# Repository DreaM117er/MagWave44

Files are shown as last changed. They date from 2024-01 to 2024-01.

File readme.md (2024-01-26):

# MagWave44

- 中文說明（Chinese Readme）。
- [英文說明（English Readme）](readme_en.md)。

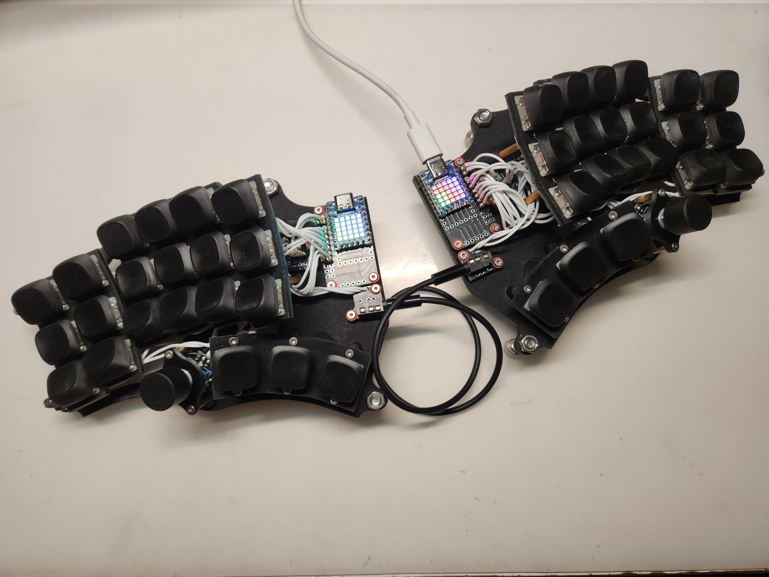
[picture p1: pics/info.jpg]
info


## 簡介

Dactyl Manuform系列的鍵盤有很多種不同的樣式、也有各式各樣的作者製作成屬於自己的曲面分離式鍵盤，但大部分的Manuform系列根據的都是原始的模型再製而成，而這些成品也不一定適合自己的雙手。而在手指長度上，無名指是屬於比較特殊的一根手指，長度介於中指跟食指之間、又或者跟食指一樣長、而又或者比食指要短都有可能，這就導致大部分的鍵盤設計在無名指上不是那麼的友好。

而我本人的手屬於無名指長介於中指及食指之間，因此根據我的雙手及原始的Dactyl Manuform設計了第一把曲面分離式鍵盤，並且使用矮軸降低鍵盤的厚度，而這把鍵盤卻有著十分難操作移動手指的致命缺失。

於是我根據這個失敗的模型重新再設計了一個模型，以iPhone用戶的外殼配件Magsafe及波浪（Wave）狀的外殼底板，再根據44鍵的按鍵總數，將這把鍵盤取名為MagWave44。

- 第一把鍵盤模型。
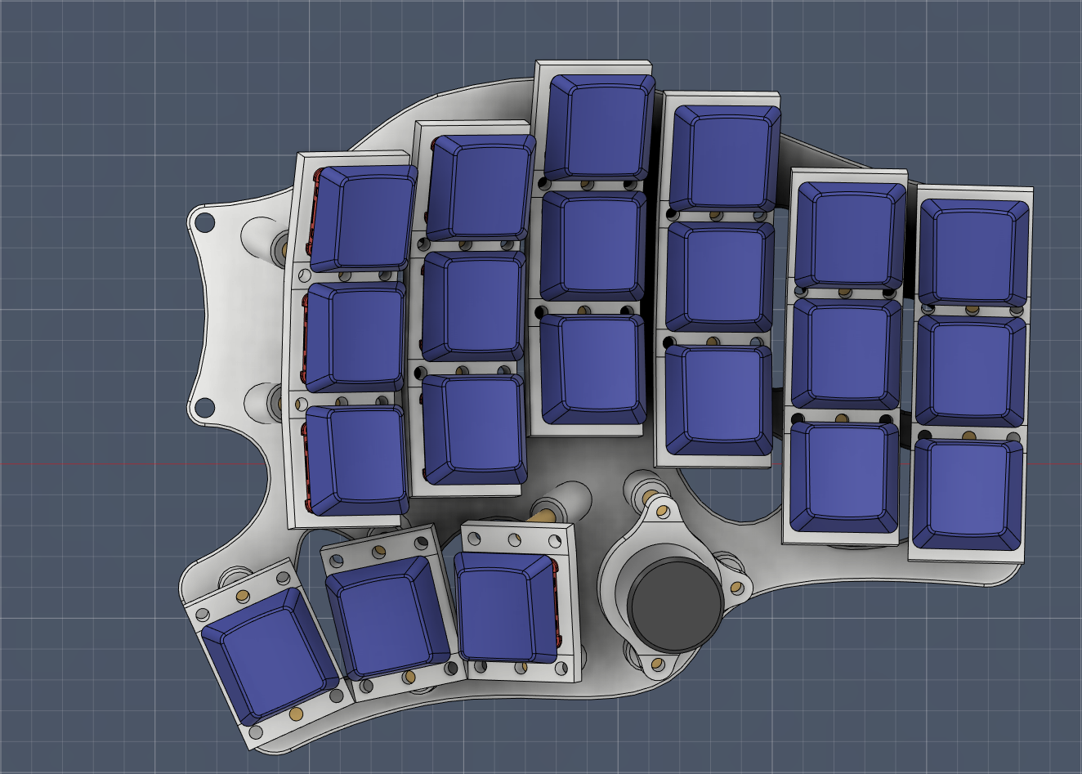
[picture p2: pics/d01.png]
des01


- 我的左手手指長度。
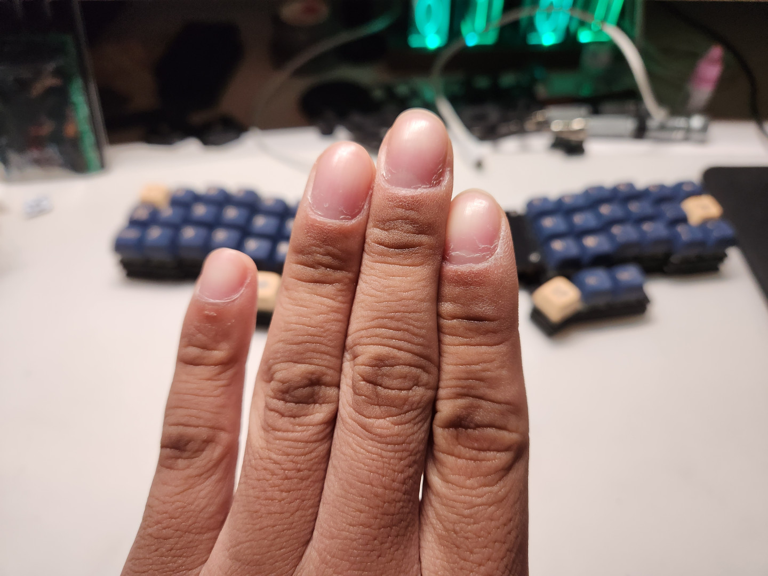
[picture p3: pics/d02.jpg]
des02


## 材料清單

### 3D列印部件

|名稱|數量|備註|照片|
|---|---|---|---|
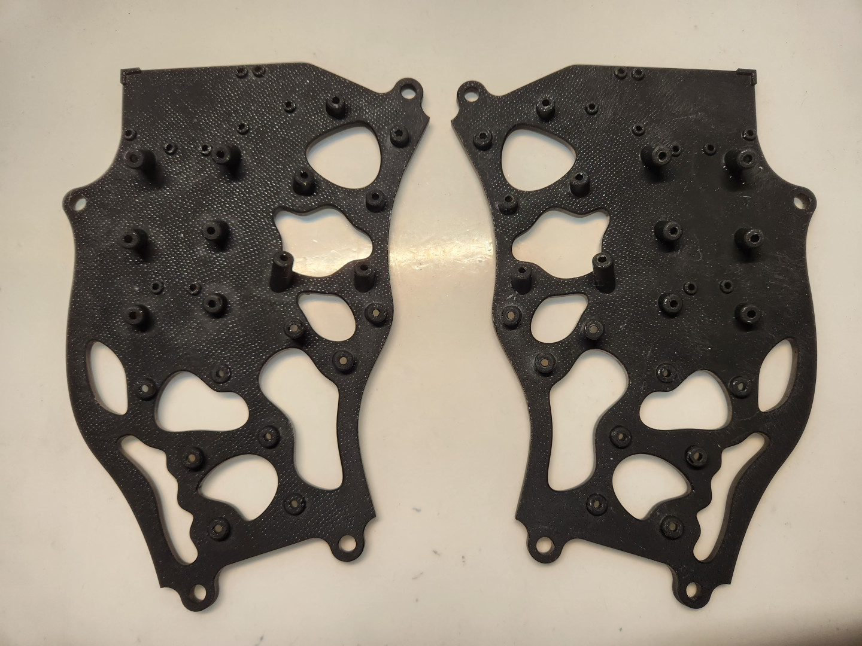
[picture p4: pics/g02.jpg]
|底板|1組|左右手||
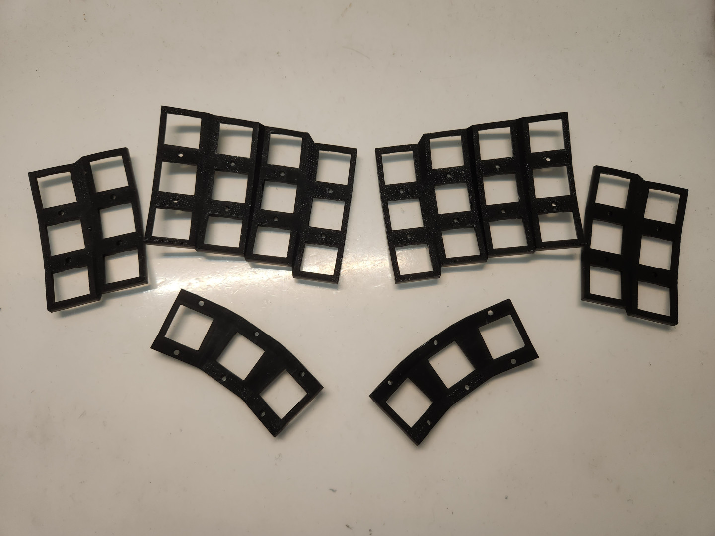
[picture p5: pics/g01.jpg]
|定位板|1組|左右手||
|旋鈕定位板|1-2片|-||
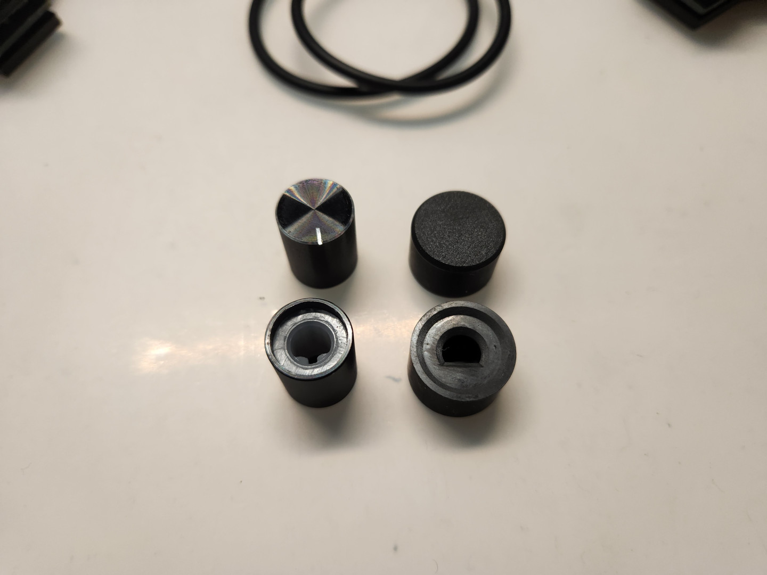
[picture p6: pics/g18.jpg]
|`D型`旋鈕帽|1-2個|-||

### 電路板

|名稱|數量|備註|正面|背面|
|---|---|---|---|---|
|單格電路板|42片|`矮軸`用|||
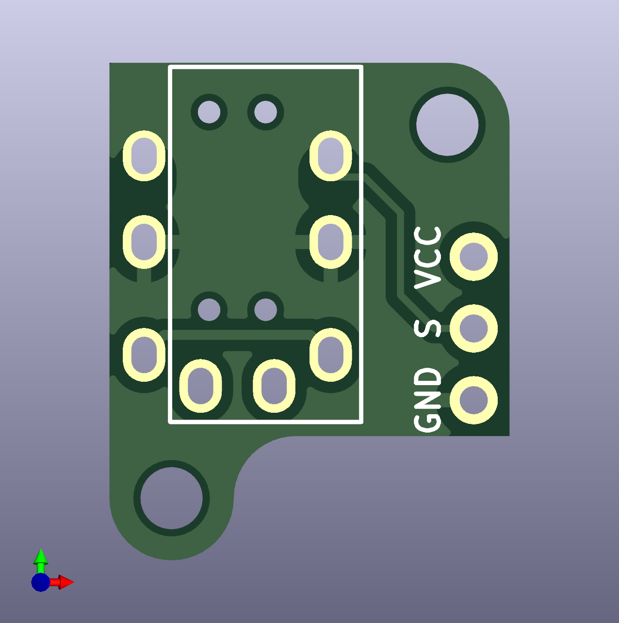
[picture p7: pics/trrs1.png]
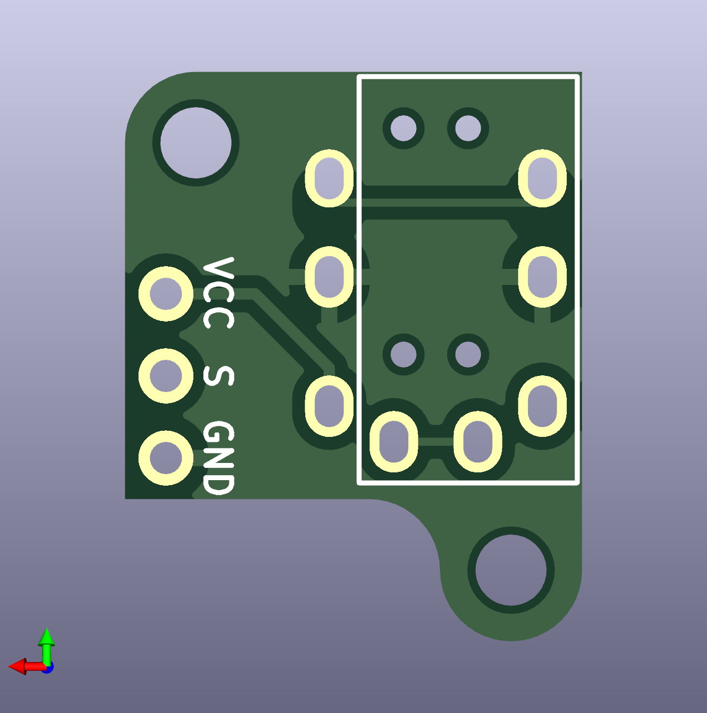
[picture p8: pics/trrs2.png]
|TRRS專用電路板|2片|-|||
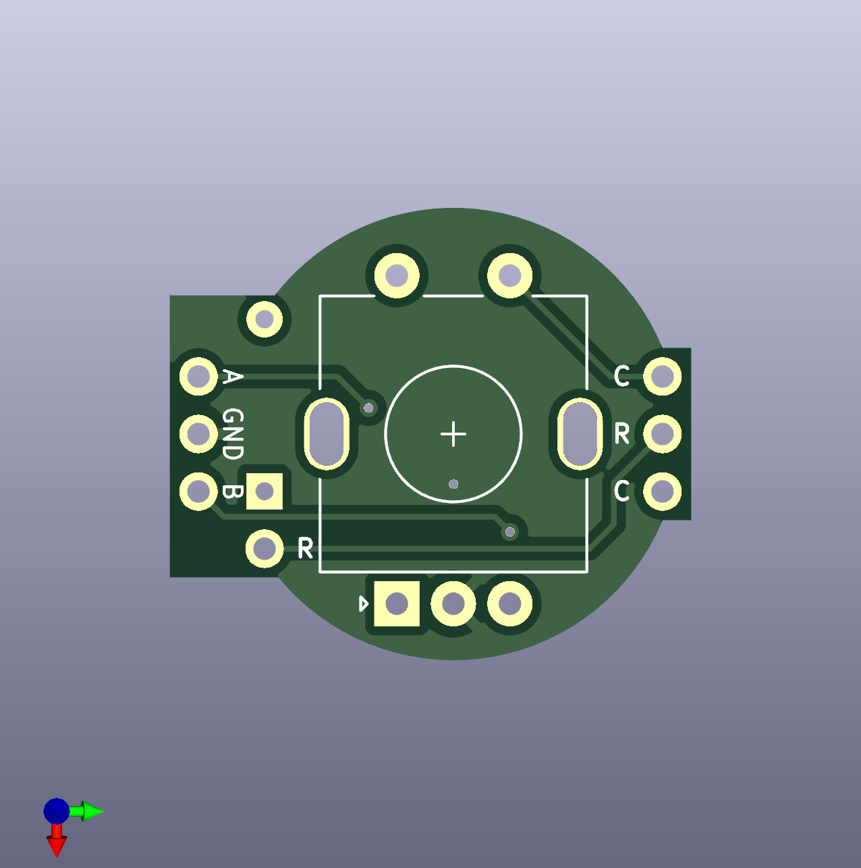
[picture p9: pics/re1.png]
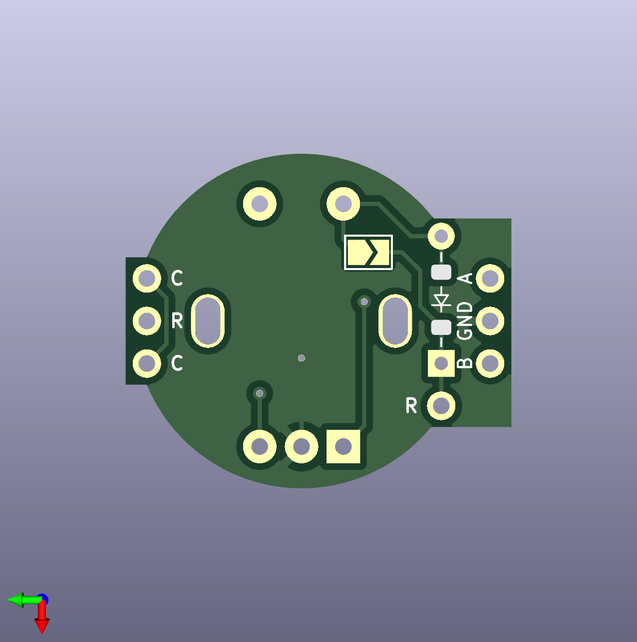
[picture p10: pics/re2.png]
|EC-11的專用電路板|1-2片|-|||
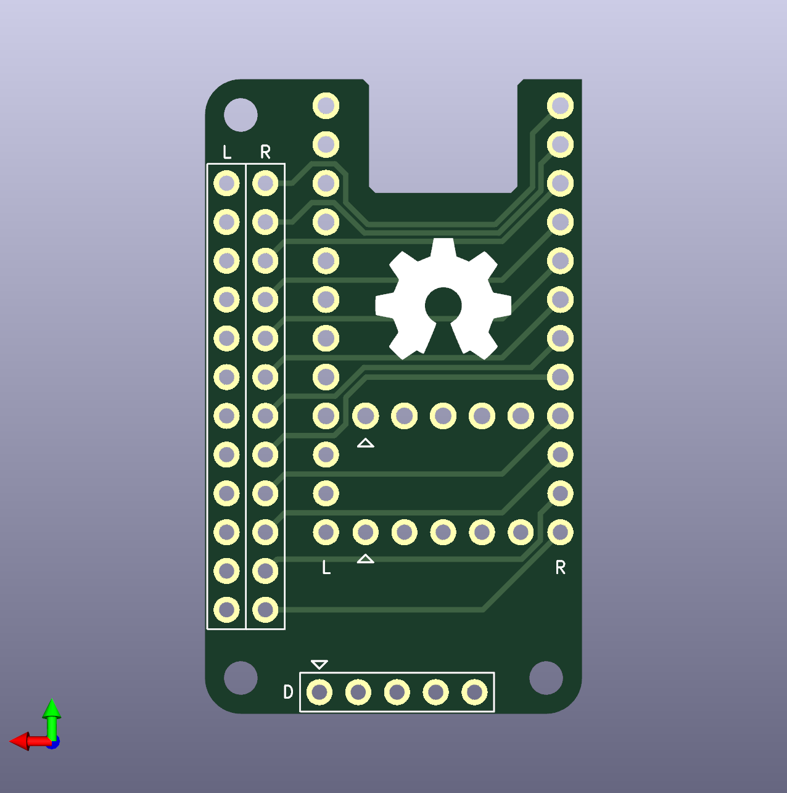
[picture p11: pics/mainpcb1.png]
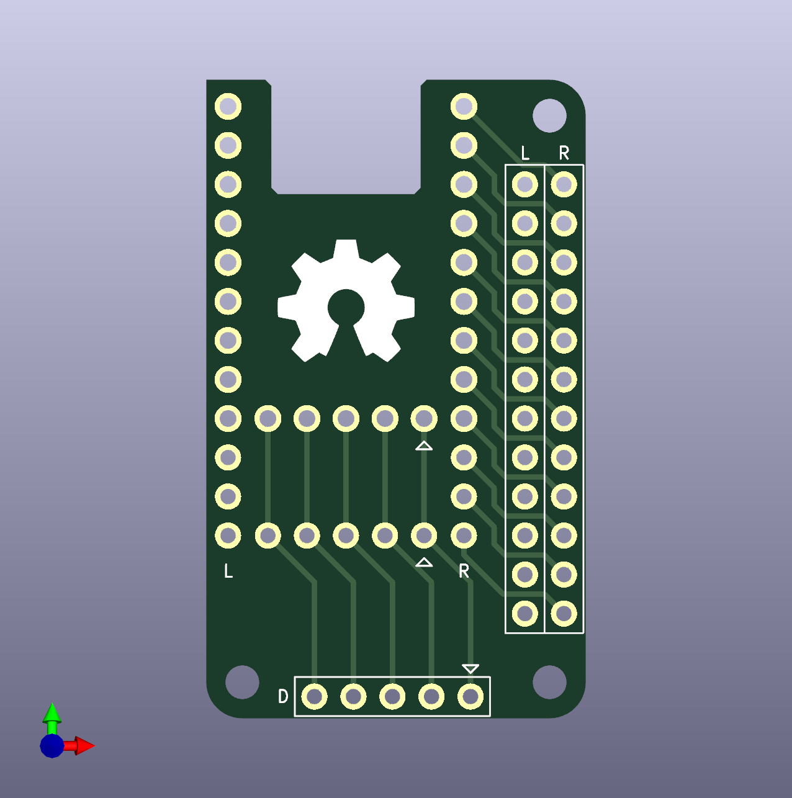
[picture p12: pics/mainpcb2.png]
|MCU電路板|2片|-|||
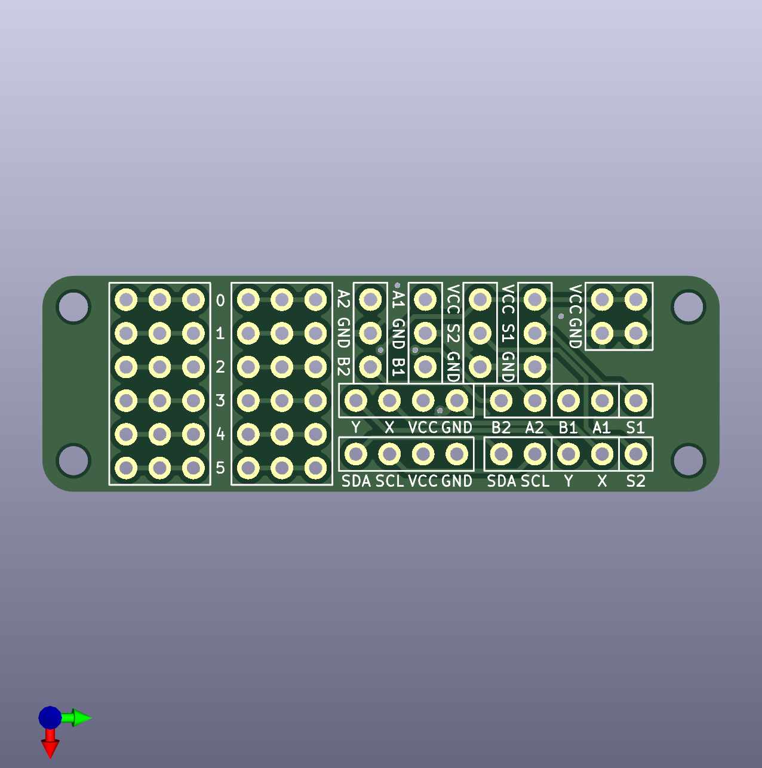
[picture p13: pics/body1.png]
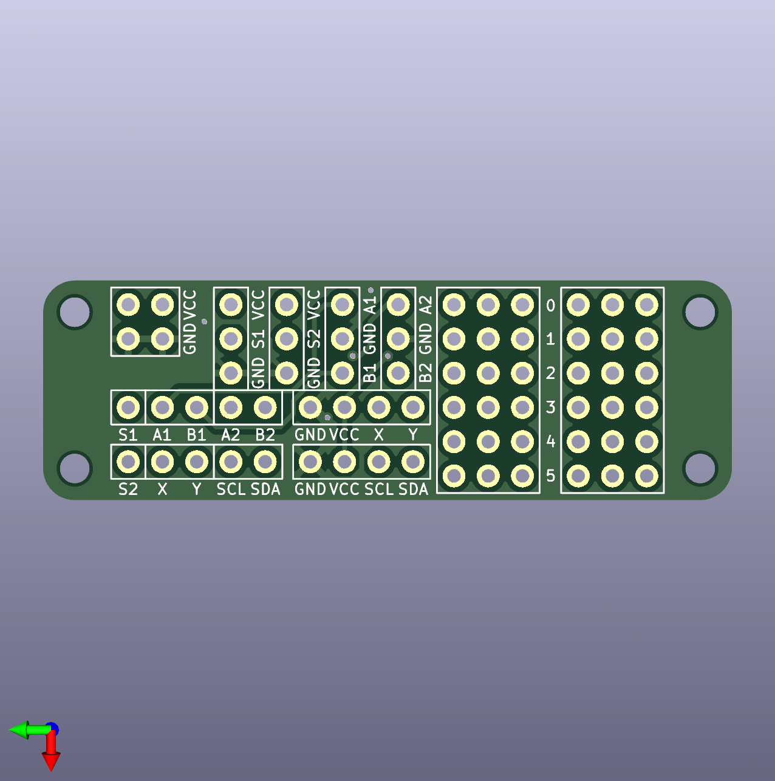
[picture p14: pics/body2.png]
|本體電路板|2片|-|||

### 螺絲零件

|名稱|數量|備註|
|---|---|---|
|微型控制器|2片|規格請查詢下方`Note`|
|`1N4148` 二極體|42-44個|`DO-35`或`SOD-123`都可|
|`TRRS`座|2個|-|
|公母圓`排針`|-|-|
|`M2x5mm` 扁頭螺絲|78-84根|-|
|`M2x8mm` 扁頭螺絲|18根|可選配，有電路板才需要|
|`M2` 六角螺母|18個|可選配，有電路板才需要|
|`M2x5mm` 雙通銅柱|16根|-|
|`M2x7mm` 雙通銅柱|8根|-|
|`M2x10mm` 雙通銅柱|6根|旋鈕零件，可選配|
|`M2x12mm` 雙通銅柱|8根|-|
|`M2x18mm` 雙通銅柱|4根|-|
|`D型` `EC-11` 旋鈕編碼器|1-2個|`高15mm`，可選配|
|`M5x8mm` 以上厚頭螺絲|8根|Tending用，可選配|
|`M5` 六角螺母|8-14個|Tending用，可選配|
|`Magsafe`引磁圈或吸磁環|2個|Tending用，可選配|
|電線或漆包線|-|-|
|矮軸|42個|-|
|1u鍵帽|42個|-|

> **Note**
>
> 可使用的微型控制器請依據自身需求做選擇，因為是完全開源的關係，你可以任意變更目前使用的GPIO腳位，如果想要按照現有韌體組裝安裝鍵盤的話，以下微型控制器是我納入清單內的，供大家參考：
> 
> ATMega32U4系列：`ProMicro 5V16M`、`Eltie-C v4`。
> 
> RP2040系列：`RP2040-ProMicro`、`RP2040-Zero`、`RP2040-Matrix`、`RP2040-SuperMini`。

## 製作前準備

> **Note**
>
> MagWave44為3D列印的曲面鍵盤，由於定位板在設計上專屬於矮軸，螺絲配件屬於比較小的M2規格，推薦使用LCD或SLA的列印機製作。

> **Note**
>
> 推薦使用工程用樹脂進行列印，確保鍵盤部件不會輕易斷裂及融化。

> **Note**
>
> 鍵盤韌體有4種可供選用，製作方式會以降低手拉線的難易度去介紹。

> **Warning**
>
> 個人操作3D列印機、使用電烙鐵工具等務必注意環境通風，避免中毒、火源、燒燙傷等危險。

- [點我進入組裝說明](guide.md)。

## 鍵盤配列

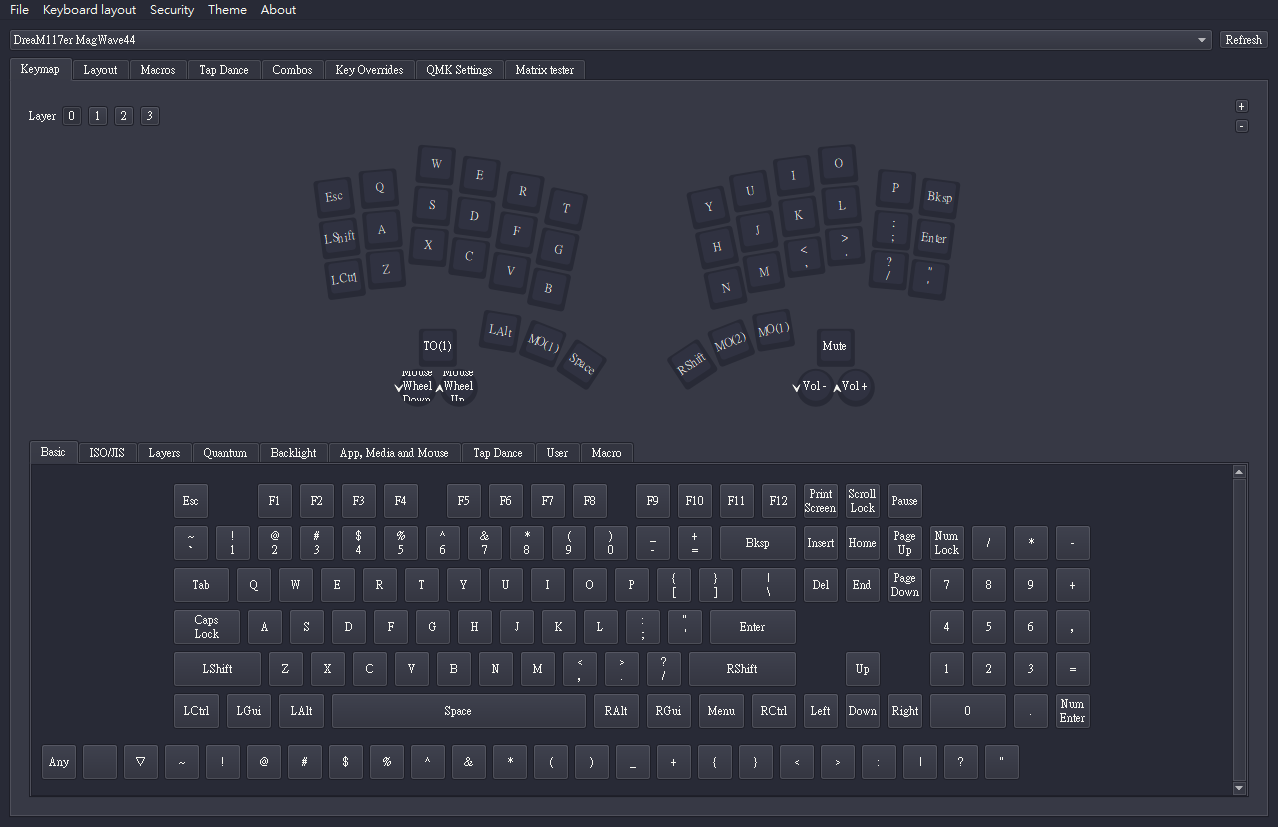
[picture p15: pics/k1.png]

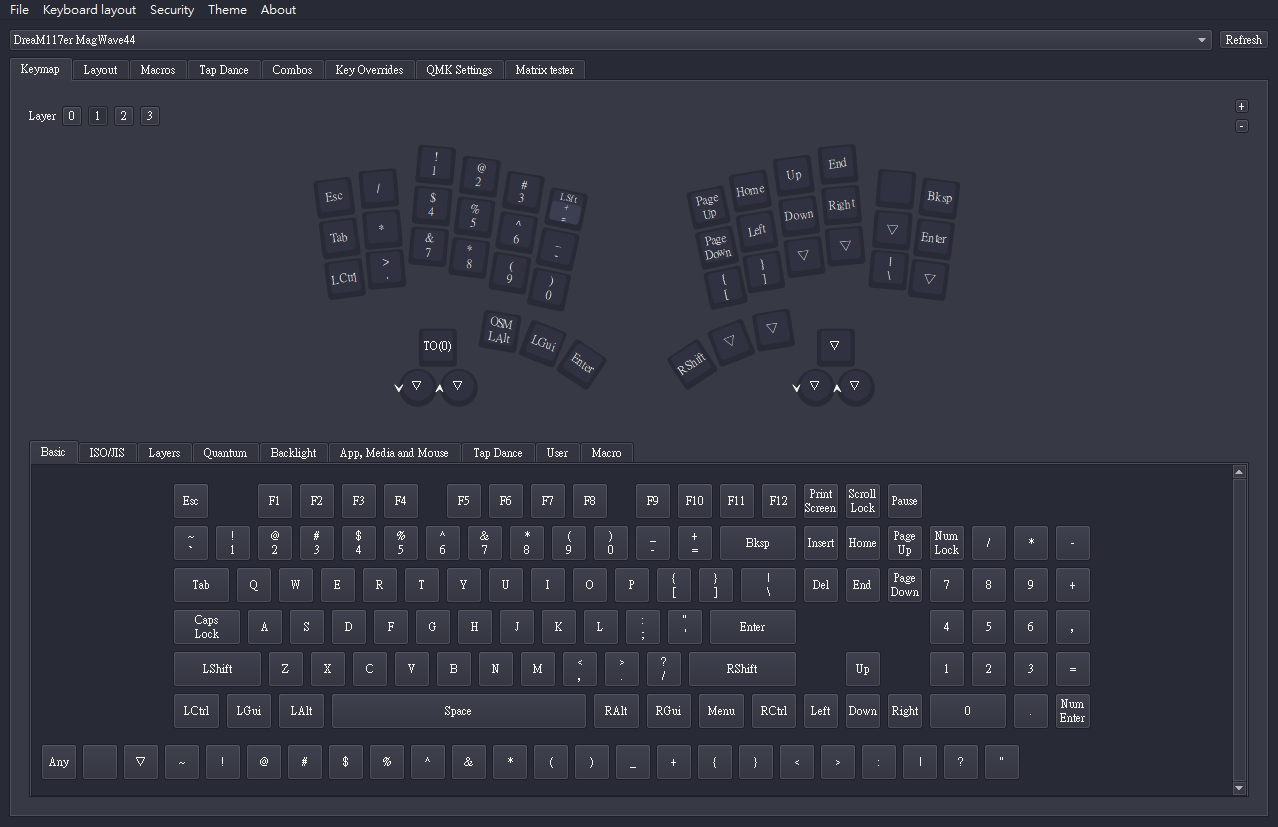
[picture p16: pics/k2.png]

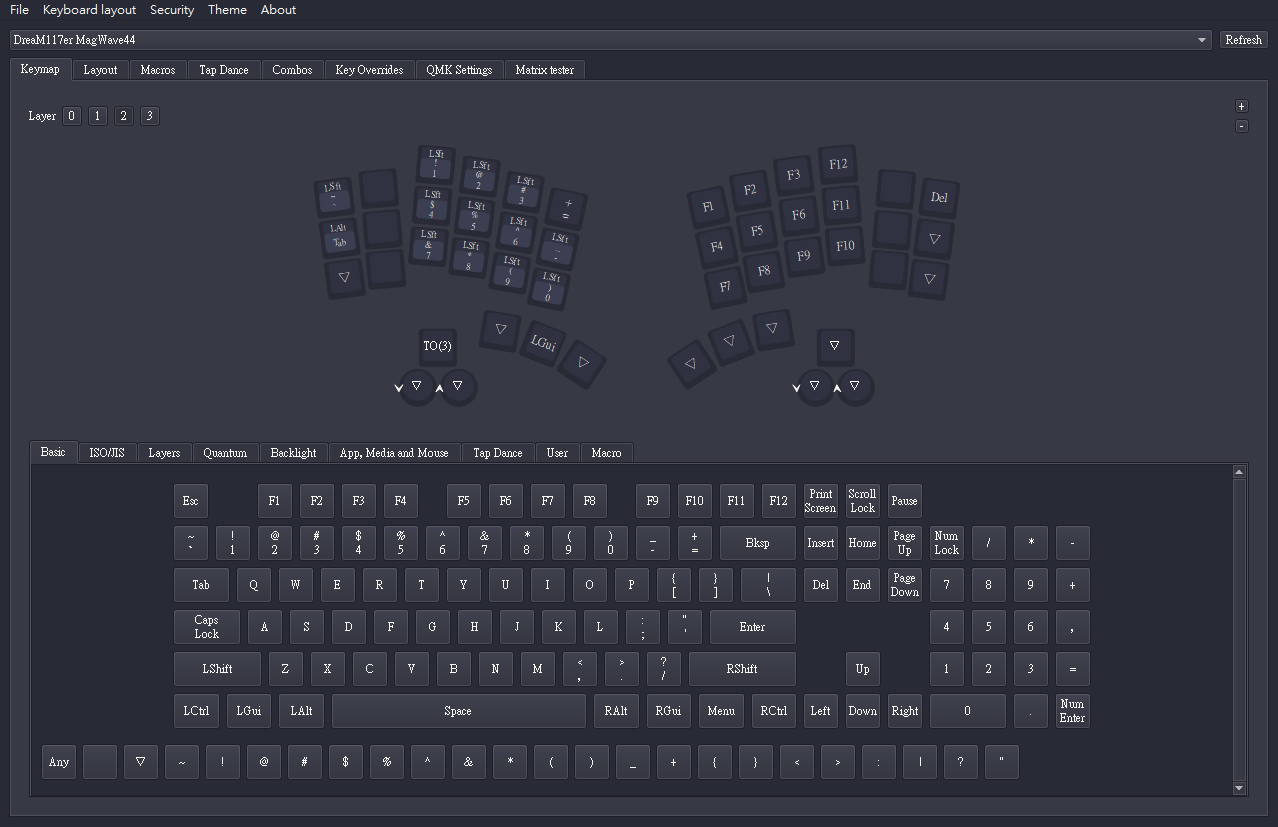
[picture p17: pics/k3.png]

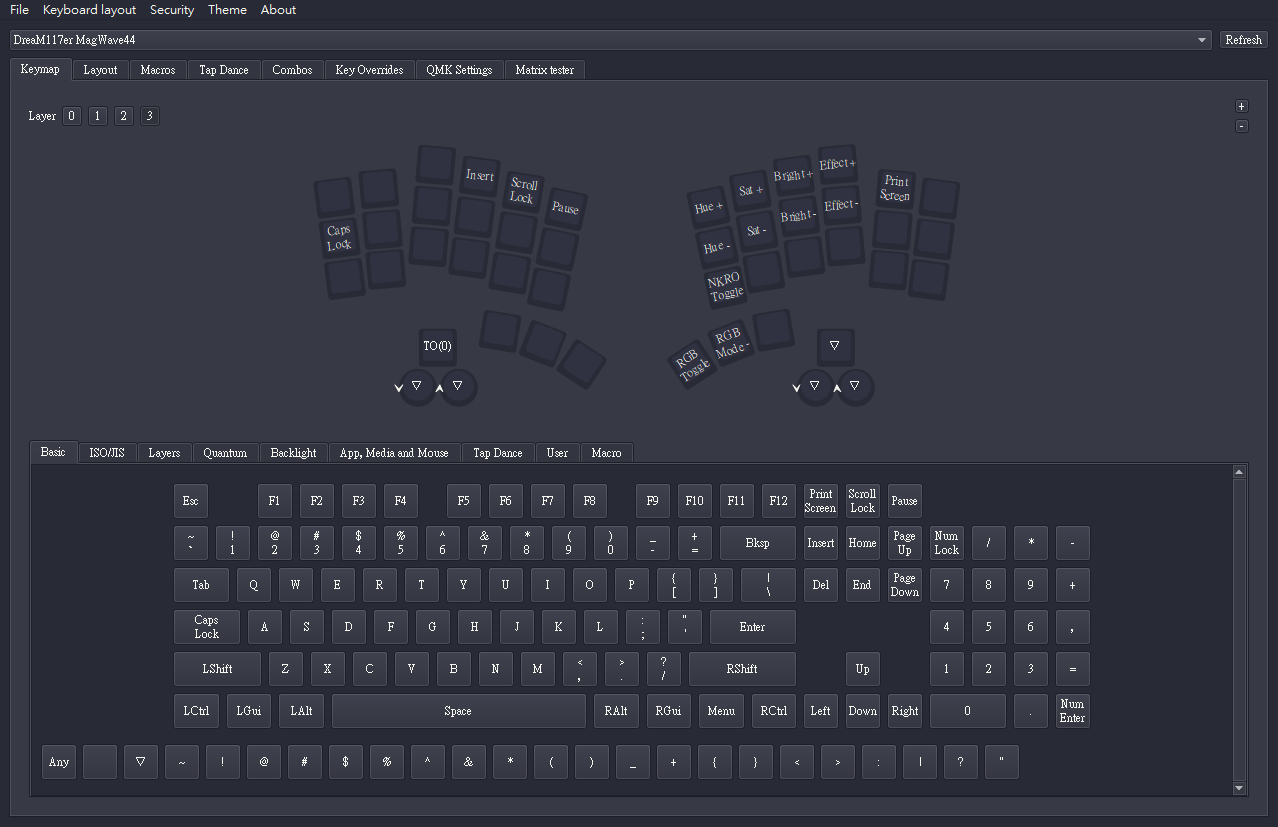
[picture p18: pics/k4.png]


## 參考及使用資料
- [QMK Firmware](https://qmk.fm/).
- [VIAL](https://get.vial.today/).
- [KiCAD](https://www.kicad.org/) version `7.0.5.`
- [JLCPCB](https://jlcpcb.com/).
- [DeepL](https://www.deepl.com/translator).
- [AutoDesk Fusion360](https://www.autodesk.com/products/fusion-360/free-trial).

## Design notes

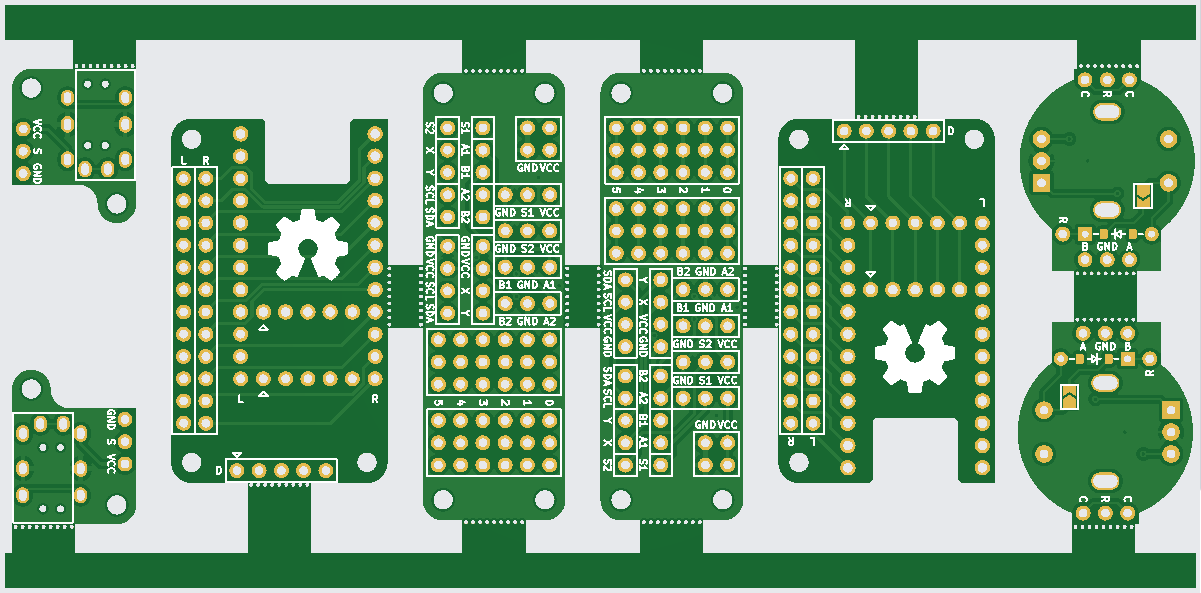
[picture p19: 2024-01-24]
pics/all1.png

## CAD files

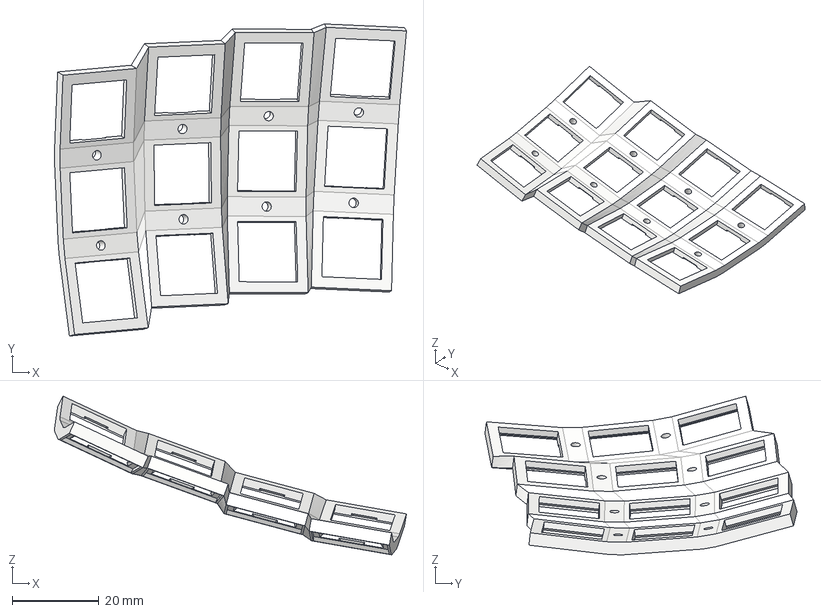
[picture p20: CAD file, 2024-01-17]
files/step/3x4 main plate.step
81.4 x 72.2 x 36.7 mm

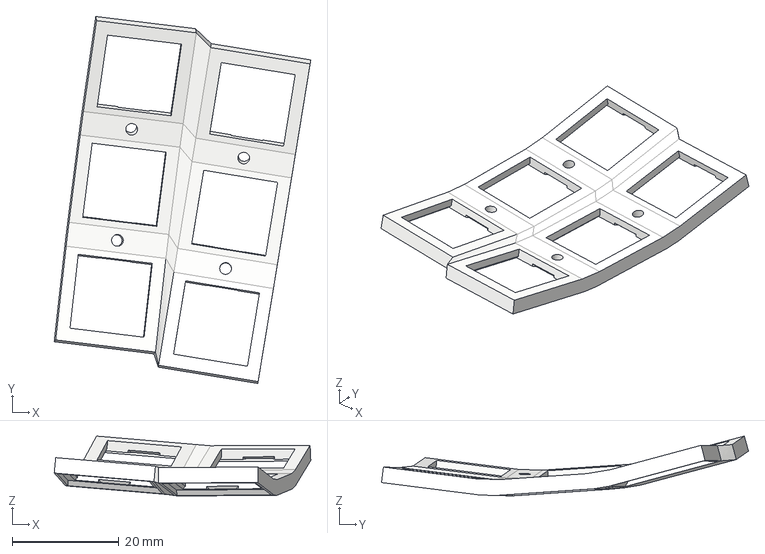
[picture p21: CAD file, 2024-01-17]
files/step/3x2 main plate.step
48.0 x 68.6 x 11.2 mm

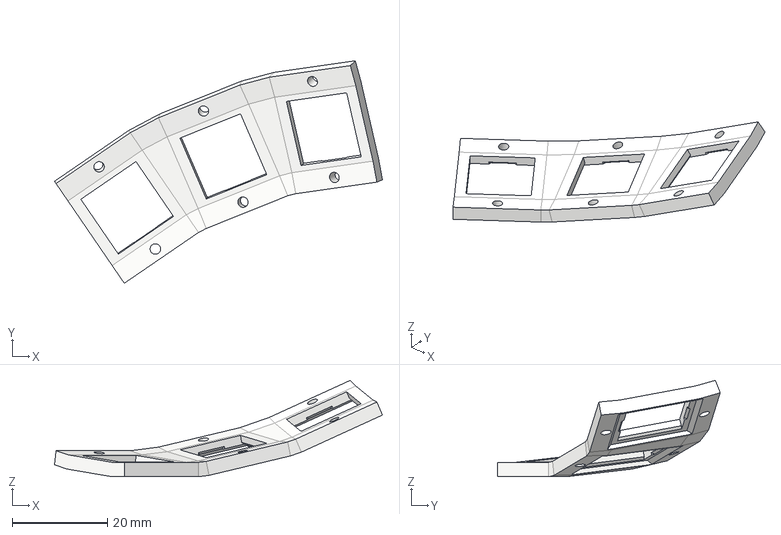
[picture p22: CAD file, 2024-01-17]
files/step/1x3 thumb plate.step
68.7 x 46.6 x 20.2 mm

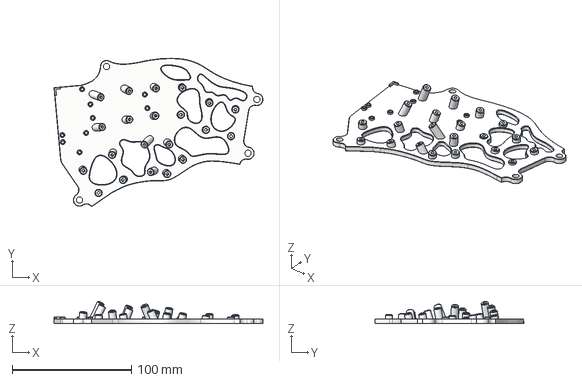
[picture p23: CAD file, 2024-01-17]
files/step/bottom.step
175.2 x 124.5 x 18.7 mm

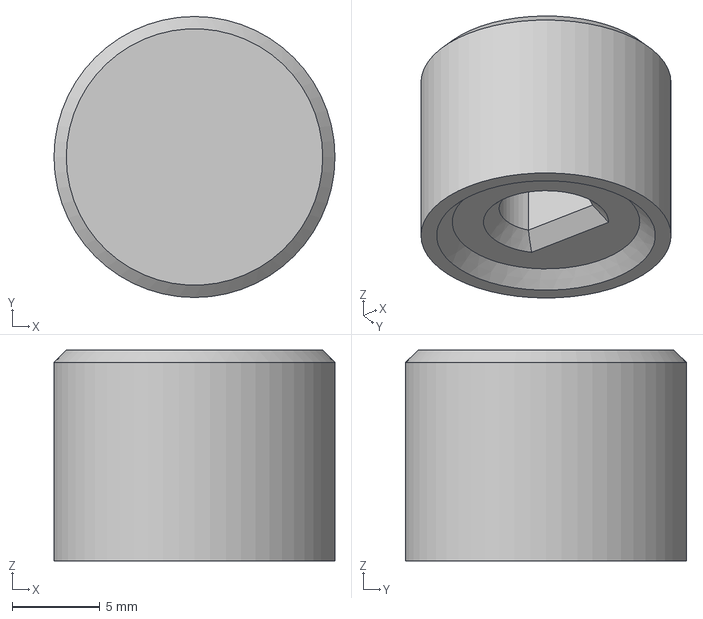
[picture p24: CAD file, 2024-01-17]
files/step/type-d h7.0mm.step
16.0 x 16.0 x 12.0 mm

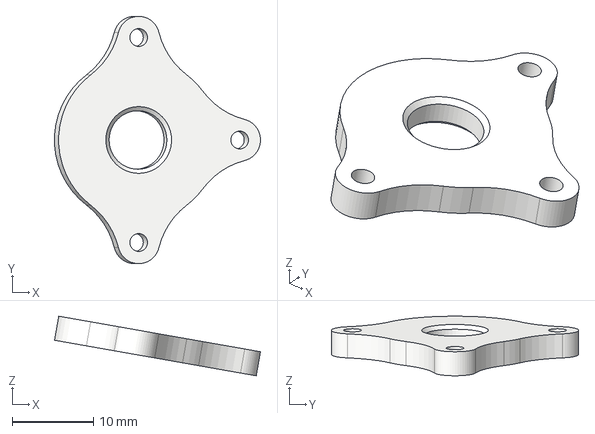
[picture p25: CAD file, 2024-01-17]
files/step/ec-11 plate.step
25.3 x 30.4 x 7.33 mm

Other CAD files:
files/stl/1x3 thumb plate.stl
files/stl/3x2 main plate.stl
files/stl/3x4 main plate.stl
files/stl/bottom.stl
files/stl/ec-11 plate.stl
files/stl/type-d h7.0mm.stl

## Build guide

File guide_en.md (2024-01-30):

# Building Guide

- [中文說明（Chinese Guide）](guide.md)。
- 英文說明（English Guide）。

## Pre-operation

- After printing out all the parts needed for the keyboard, first take out the bottom parts and spacers ,follow the photo instructions for installing the posts in their proper locations.

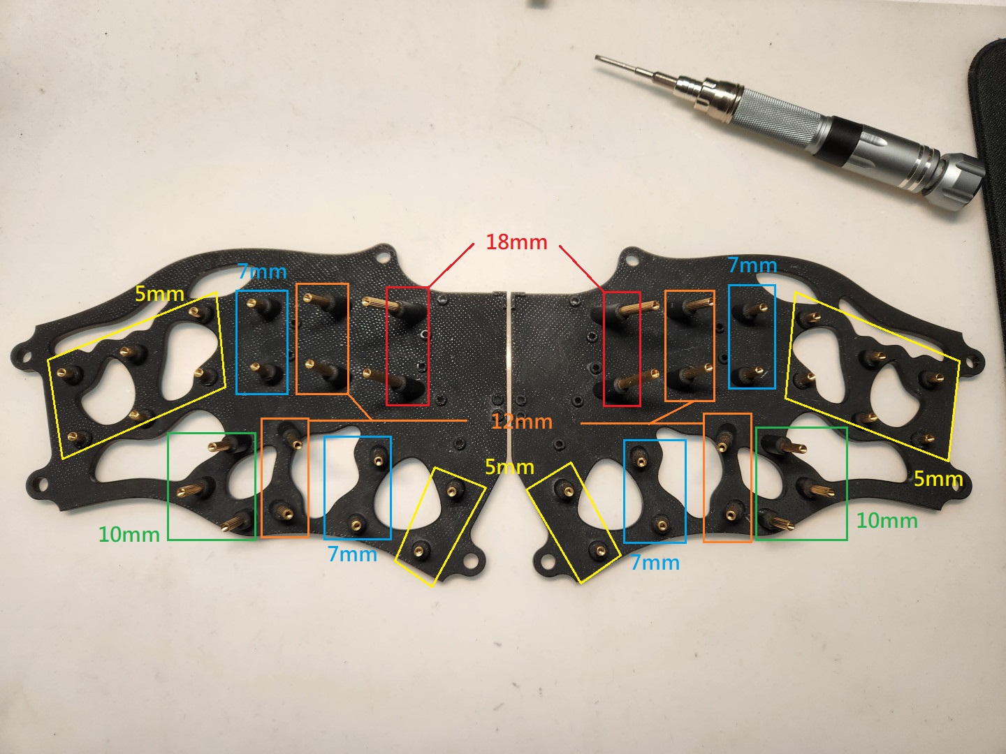
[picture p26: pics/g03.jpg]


- Next, install the switches onto the plate and set them aside temporarily when you are done.

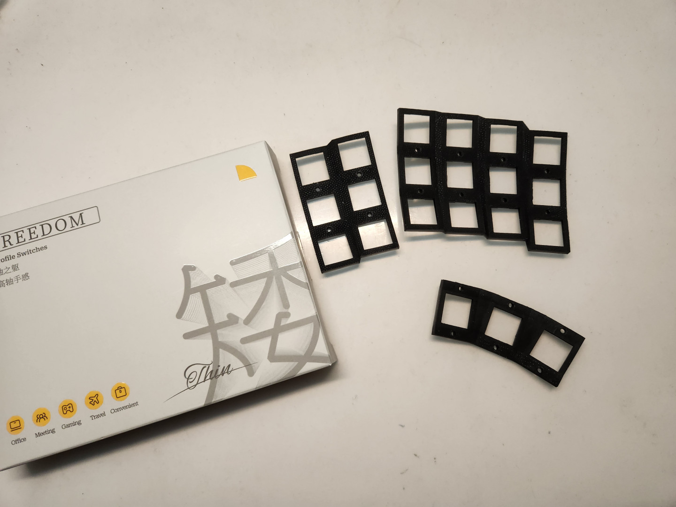
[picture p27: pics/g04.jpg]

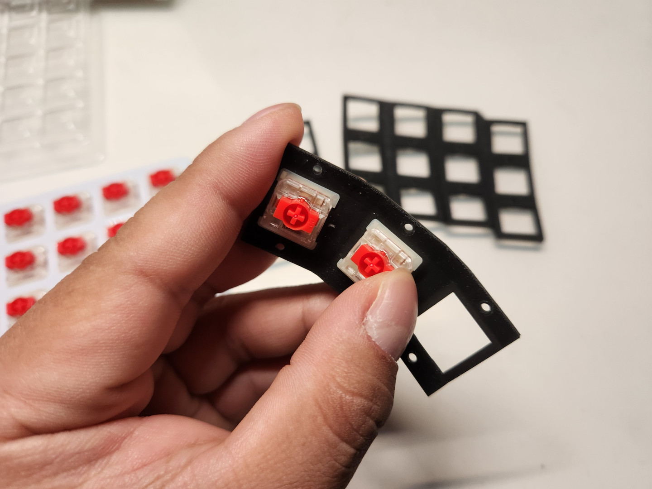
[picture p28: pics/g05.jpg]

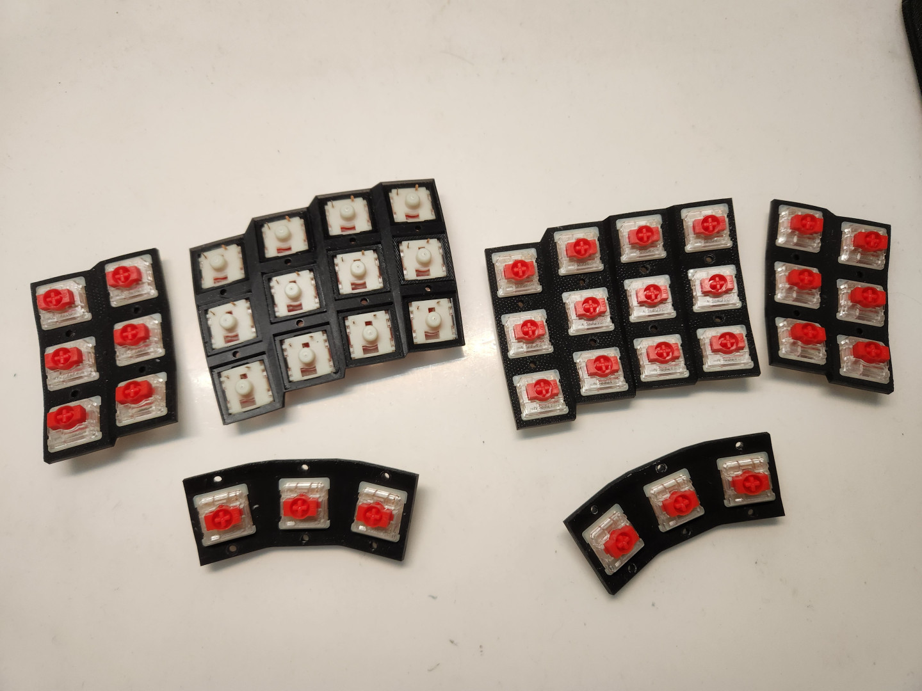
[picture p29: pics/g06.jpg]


## Diodes and Single PCB

- Here is a brief explanation of the orientation of the diode on the single PCB, please follow the photo below to install the diode on the PCBs.

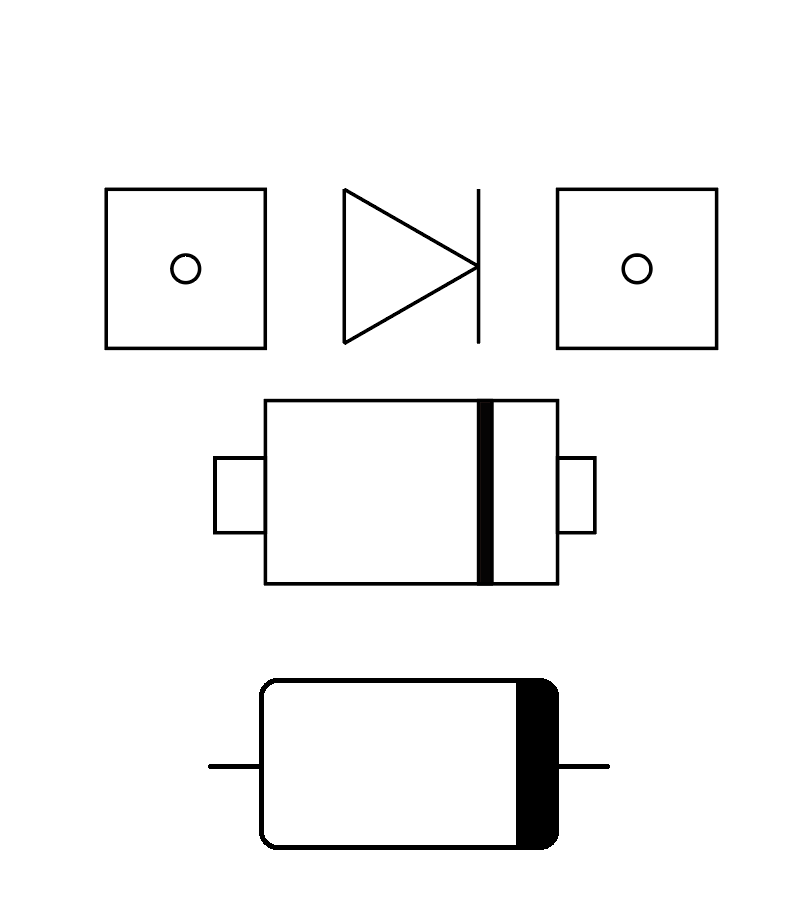
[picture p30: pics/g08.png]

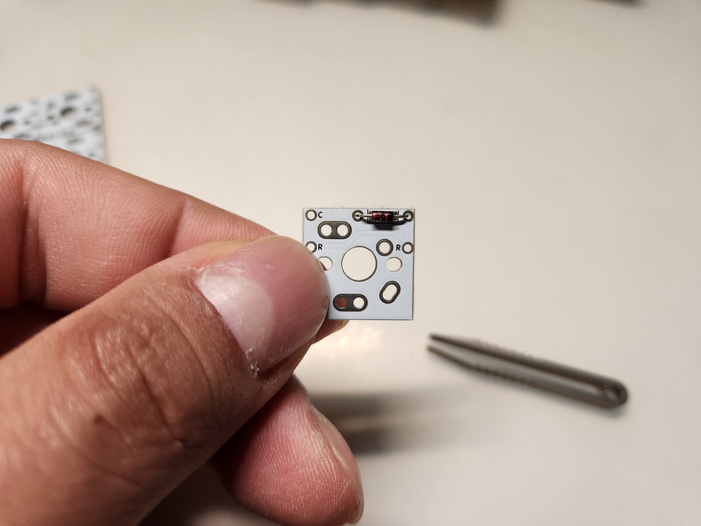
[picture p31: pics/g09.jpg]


- Next step you need to solder the diodes, then cut off the useless feets.

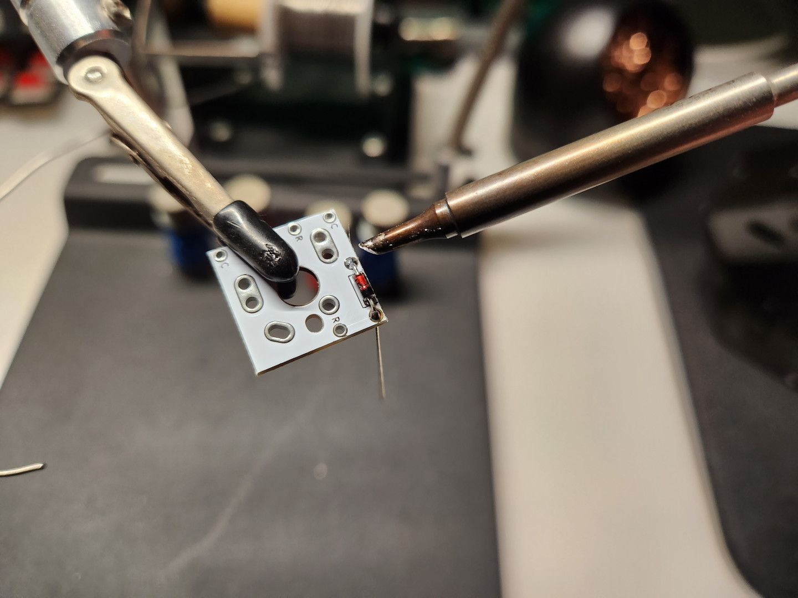
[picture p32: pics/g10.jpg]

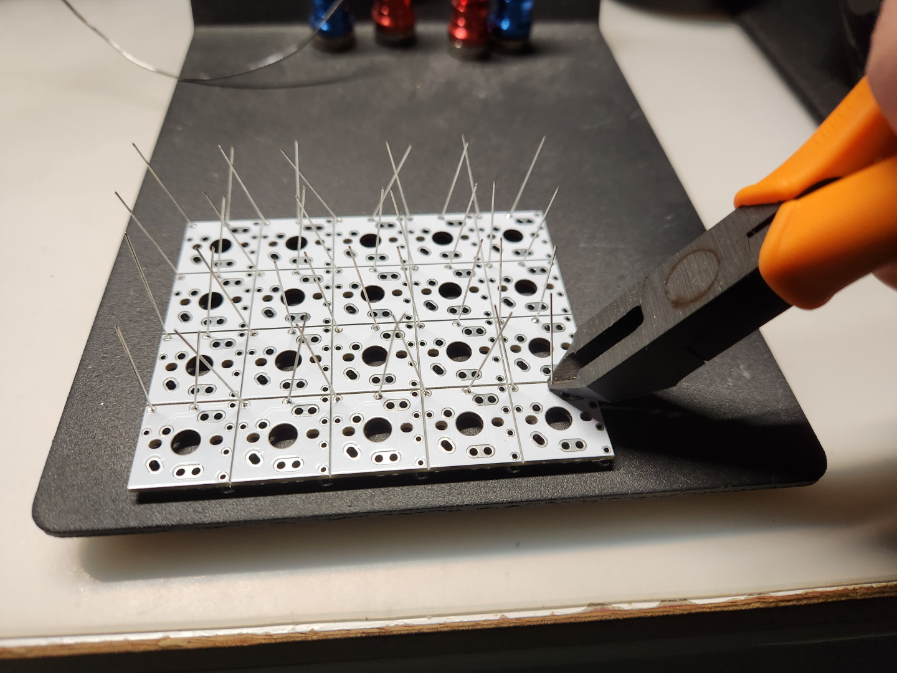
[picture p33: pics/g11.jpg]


- The completed single PCBs are then mounted onto the positioning plate and soldered in place.

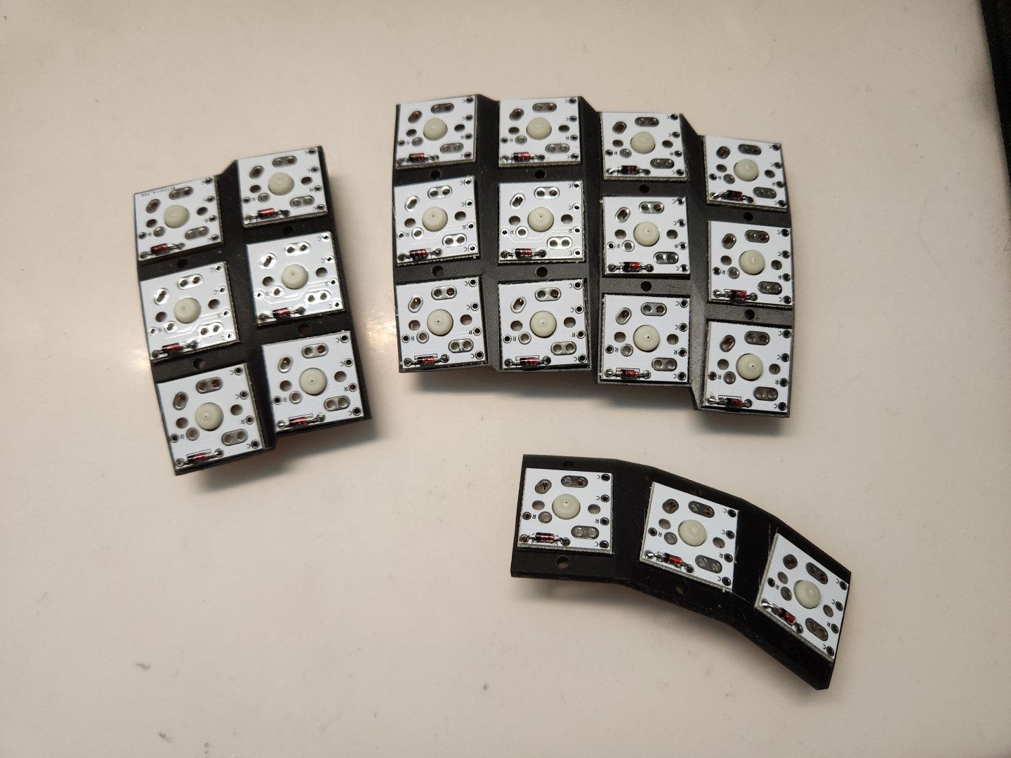
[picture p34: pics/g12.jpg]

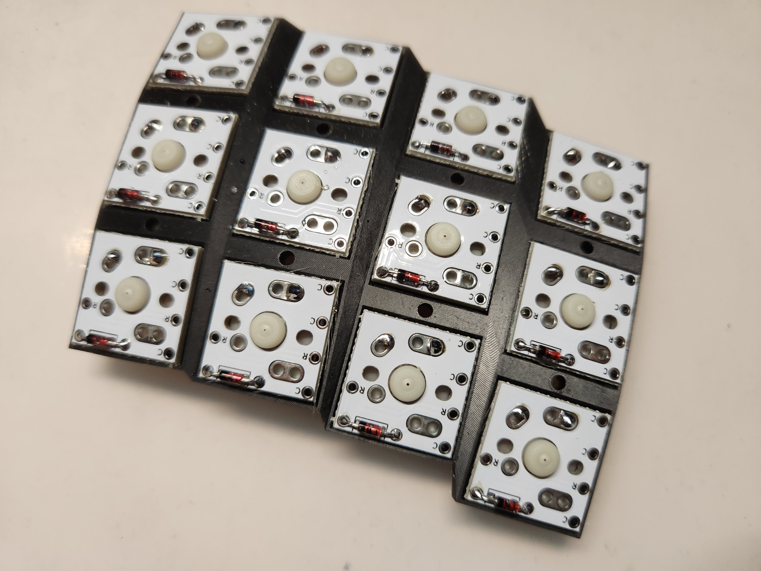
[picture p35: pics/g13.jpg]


- It has a switch on the PCB for EC-11, don't forget to install the diode on it.

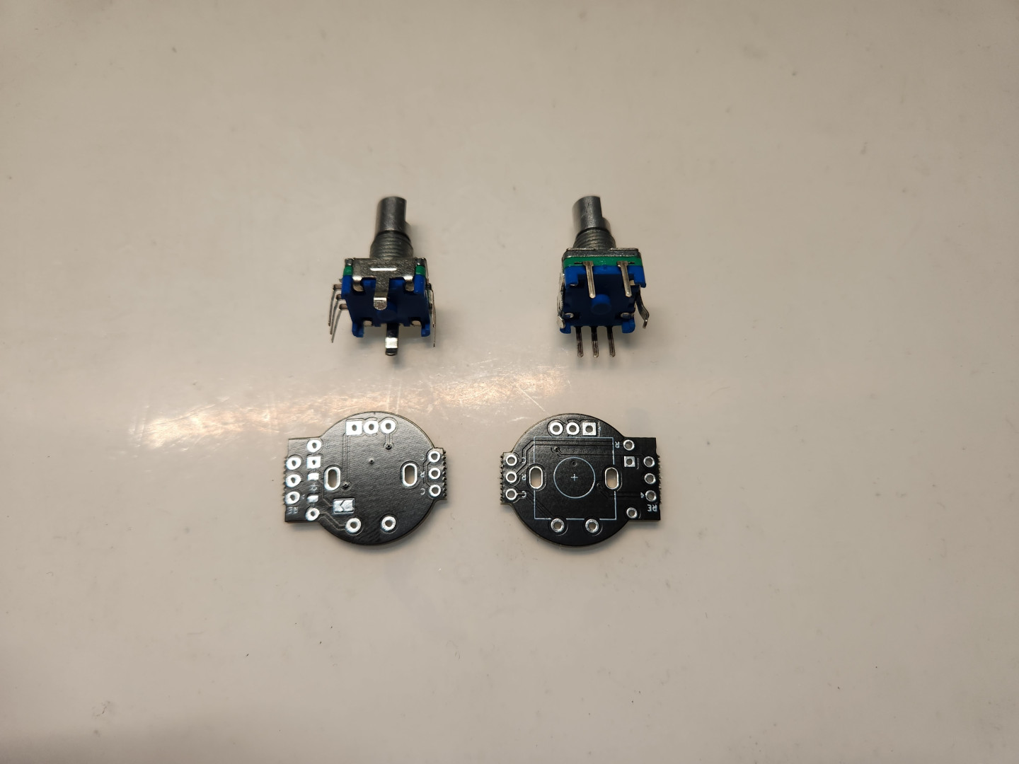
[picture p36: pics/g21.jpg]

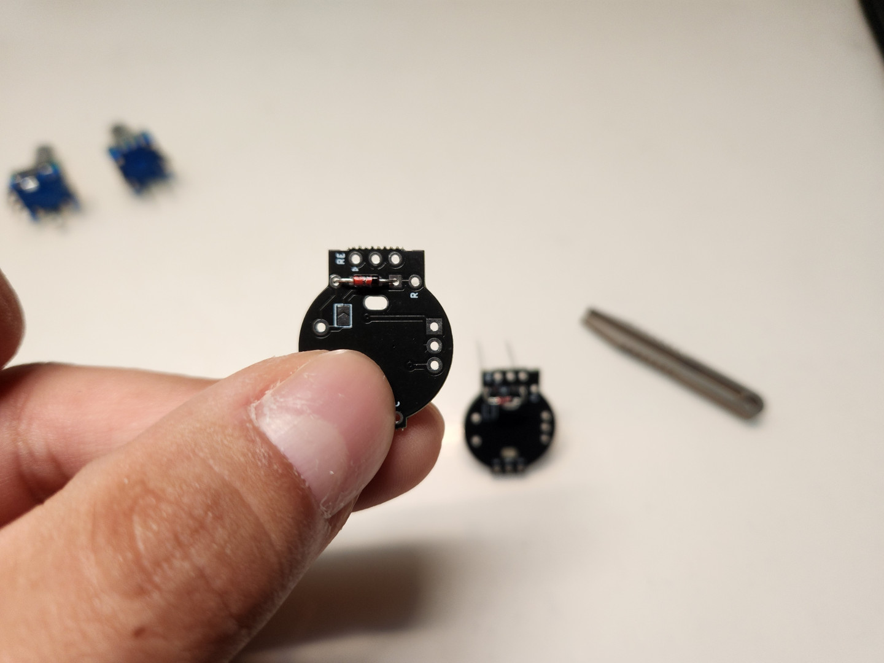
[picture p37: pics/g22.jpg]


- After installing the diode, you can solder EC-11 on the board first.

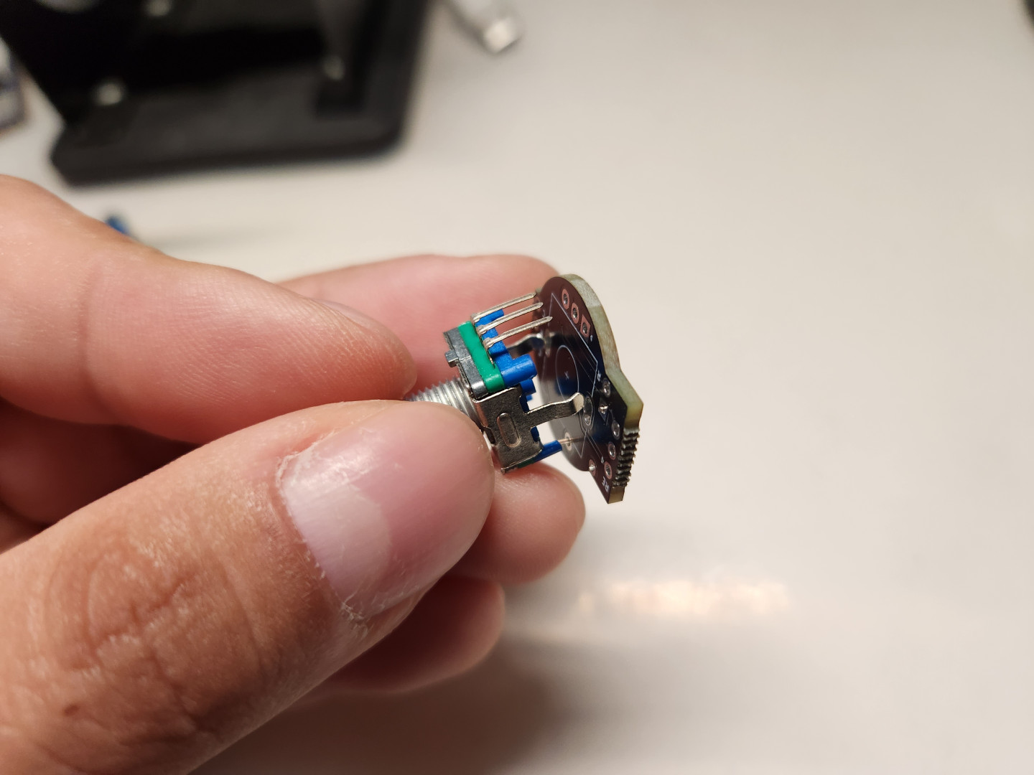
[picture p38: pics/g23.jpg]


## Link Keyboard Matrix

- The following photo shows the matrix of the MagWave44. Since all the plates are divided into 6 pieces, first we need to connect the single PCBs in the photo with wires.

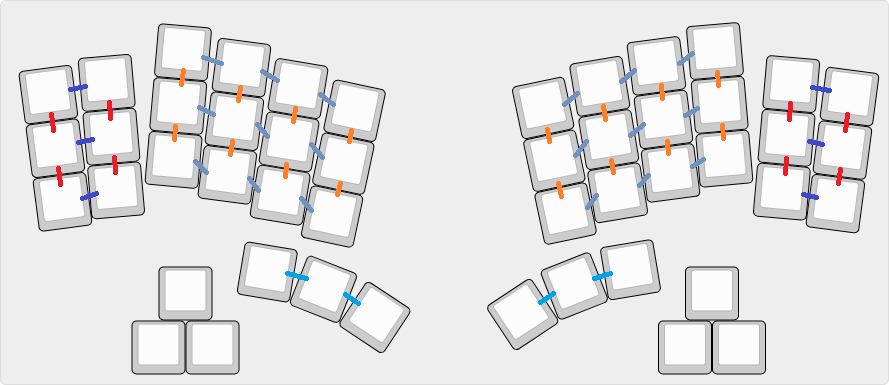
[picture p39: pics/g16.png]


- That's how it feels when it's done.

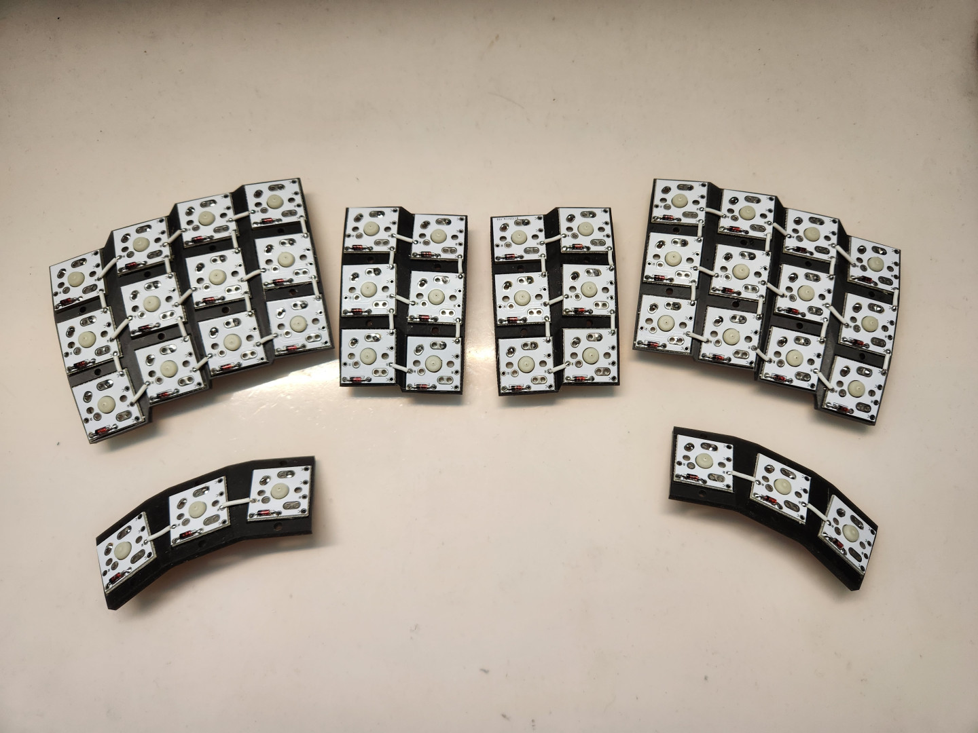
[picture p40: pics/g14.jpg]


## PCBs

> **Note**
>
> The part of the main board contains `MCU`, `Body`, `EC-11` and `TRRS`, please prepare them first.

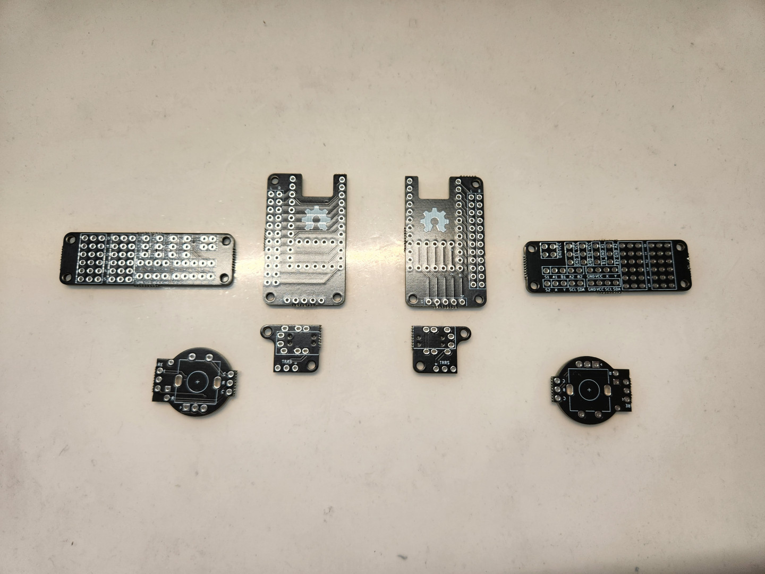
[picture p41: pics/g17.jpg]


- The MCU board part is not divided into front and back, you can adjust the direction, this time it is to build a split keyboard, the part of the bus connector is facing the left and right side respectively.

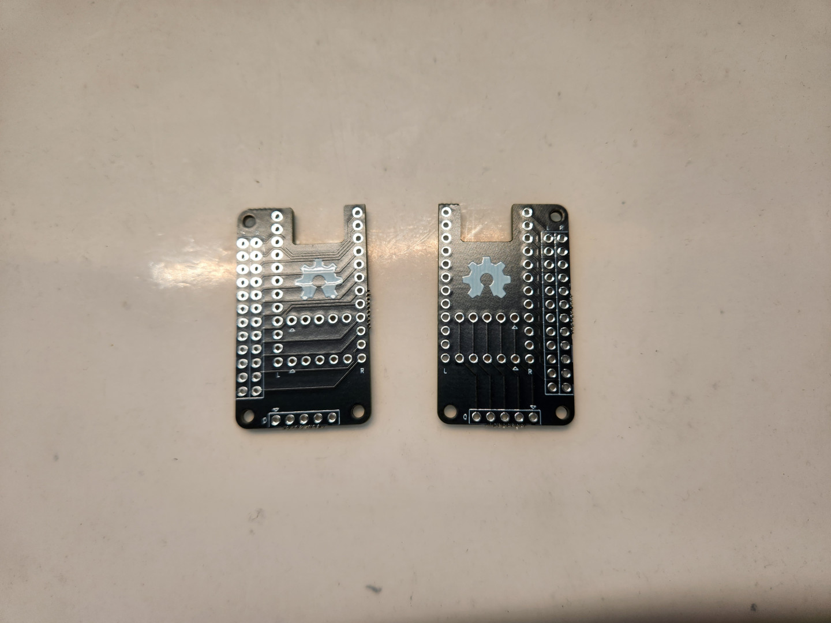
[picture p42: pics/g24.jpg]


- Next, solder the MCU (here I used `RP2040-matrix` to be MCU) on the MCU board in the desired way.

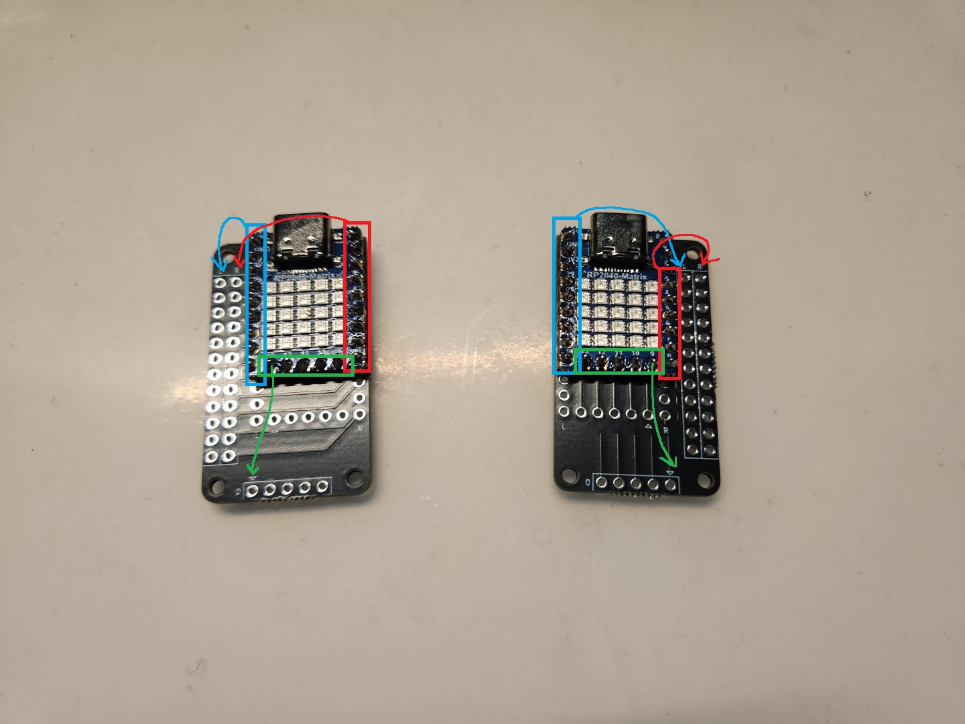
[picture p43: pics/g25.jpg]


> **Note**
>
> After solder the MCU on the MCU board, the `left side pin` will lead to the `L side`, the `right side` will lead to the `R side`, and the `bottom side` will lead to the `D side` below, and the direction of the `arrow` will be the position of the pin as the direction reading.

- The `TRRS jacks` are then soldered to the dedicated PCB board.

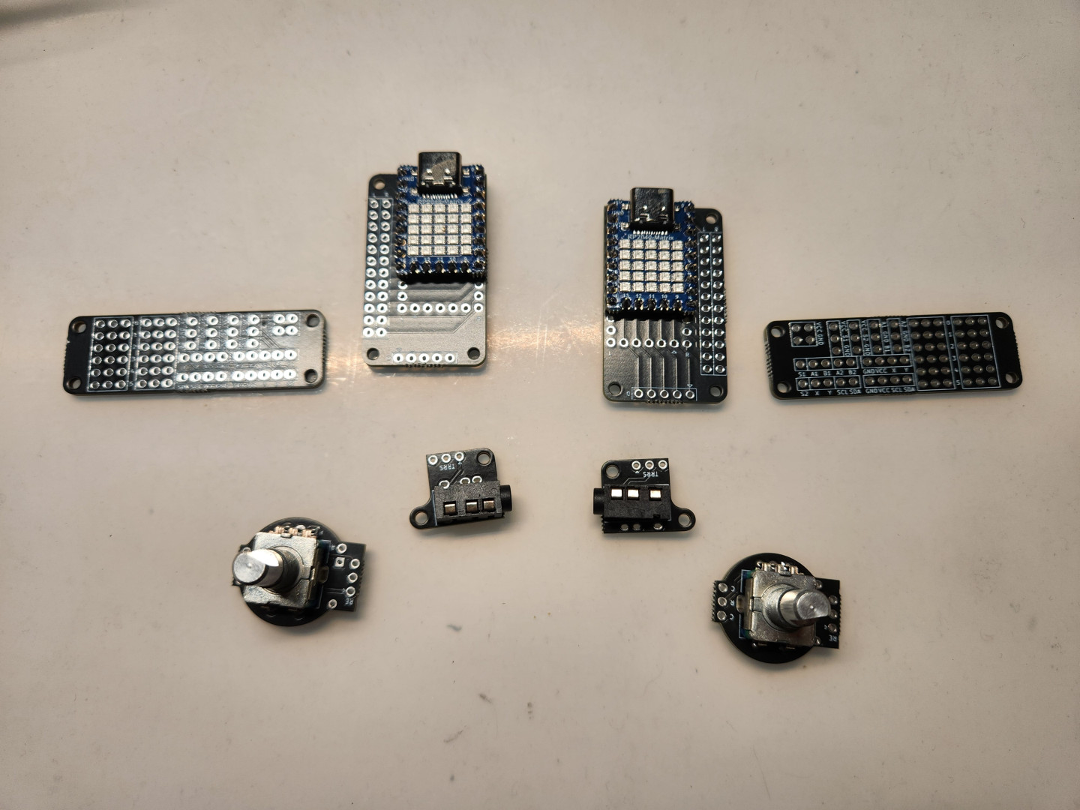
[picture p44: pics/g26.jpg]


> **Note**
>
> The left and right sides of the MCU have several usable IOPins, so solder as many female pins as you want to the bus connector labeled.

> **Note**
>
> The following photo shows the main functions of the board, MagWave44 will use `Power`, `TRRS` (`VCC`, `S1`, `GND`), `Signal` (`S1`, `A1`, `B1`), `Rotray Encoder` (`A1`, `GND`, `B1`), and `Matrix` (`Row` and `Col`), and will be left and right side of the board the corresponding row of pins female sockets soldering fixed.

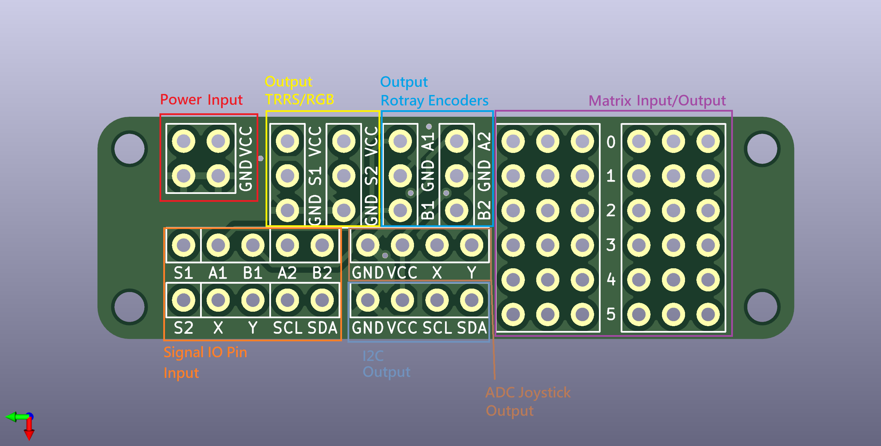
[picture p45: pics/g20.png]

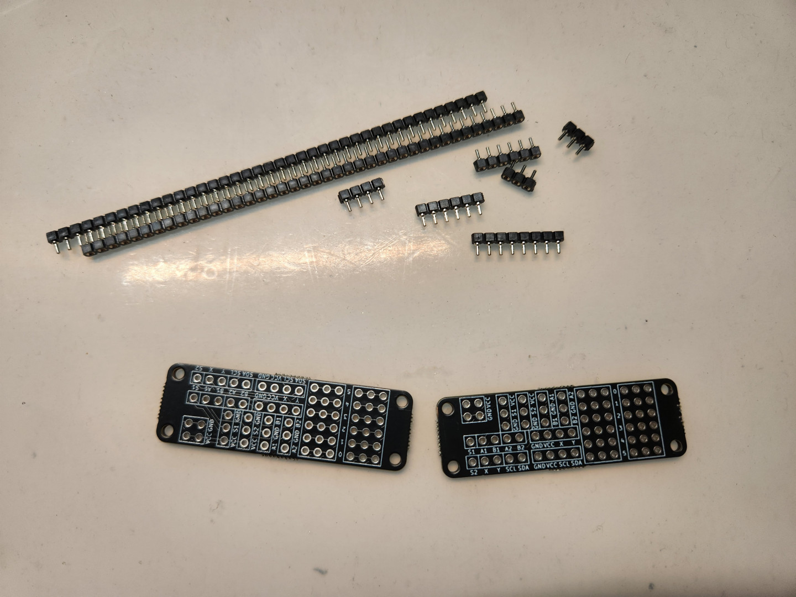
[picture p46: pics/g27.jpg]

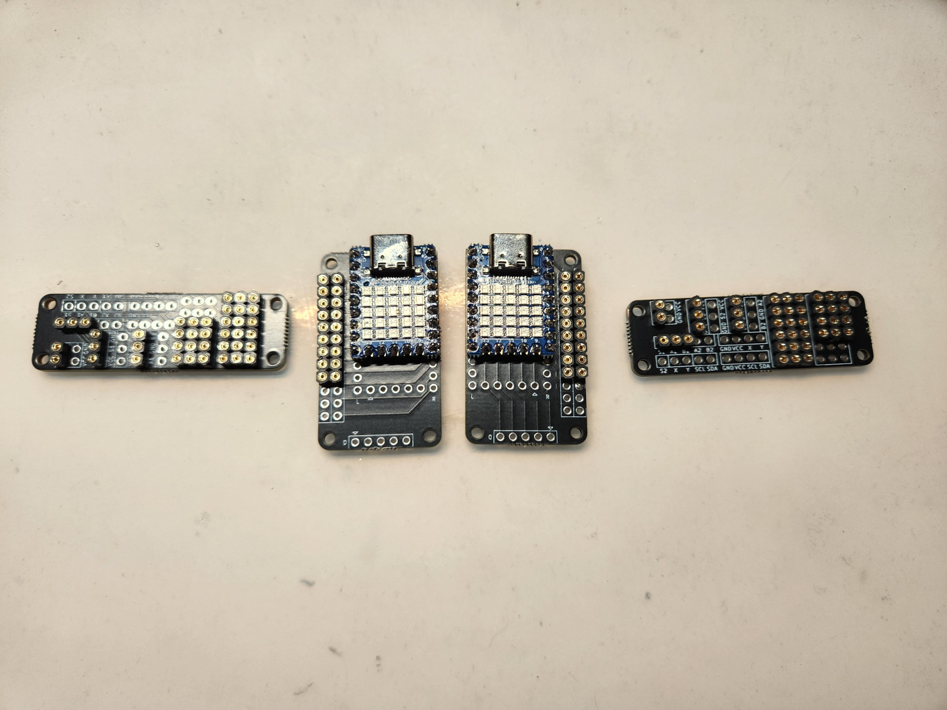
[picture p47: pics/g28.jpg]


- Then fasten them to the bottom case with `M2x8mm screws` and `M2 nuts` respectively. (Here I have the matching `washers`, you can use it according to your needs)

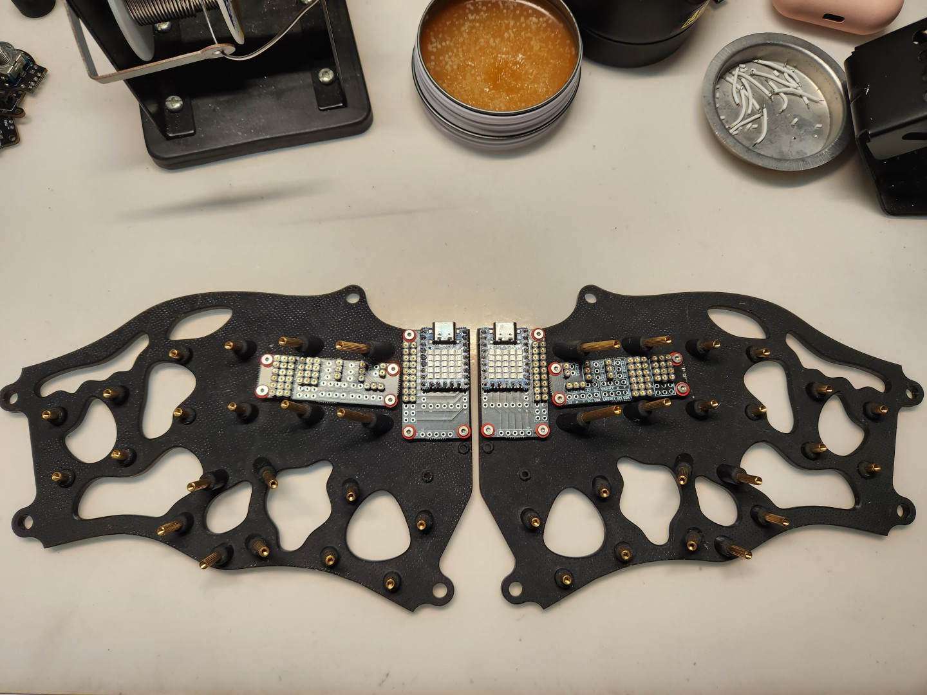
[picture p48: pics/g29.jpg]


## Wiring Principle

> **Note**
>
> If you want to wire the MCUs according to the MagWave44 `firmwares`, the following photo shows how to wire the MCUs in an easy way:

|MCUs|Photo|
|---|---|
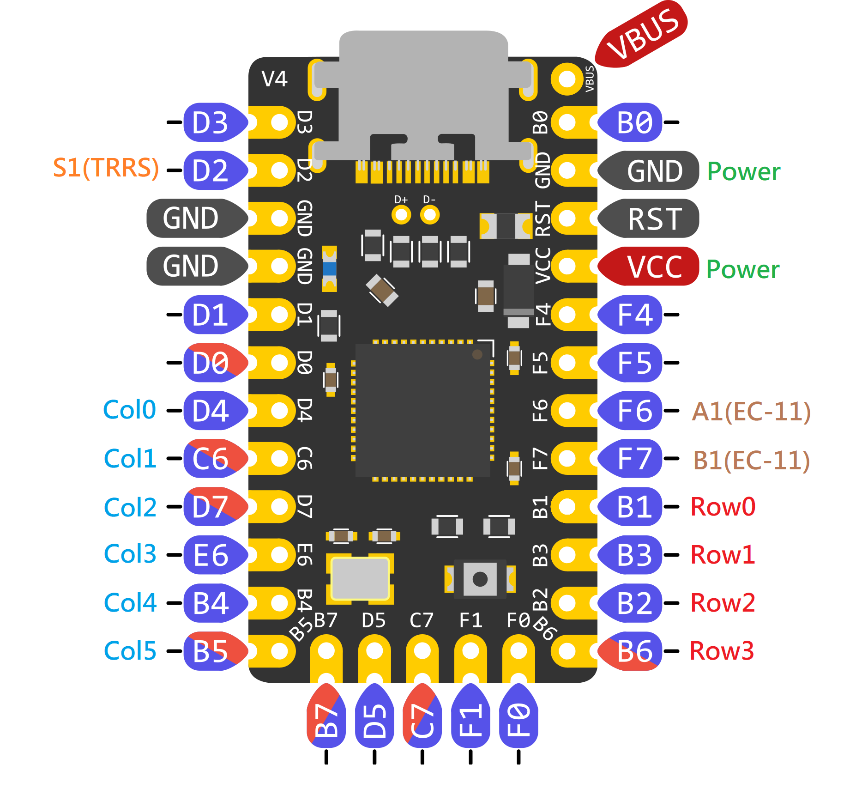
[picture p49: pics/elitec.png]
|`ATMega32U4 ProMicro`, `Elite-C`||
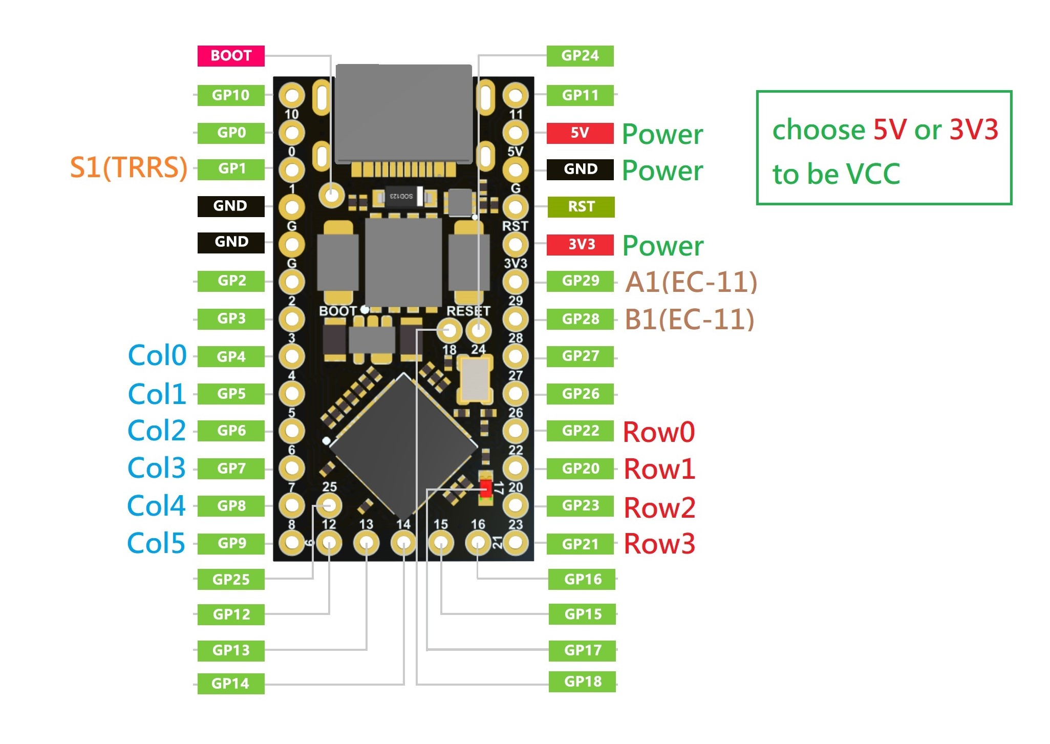
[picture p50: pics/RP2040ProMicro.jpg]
|`RP2040 ProMicro` series||
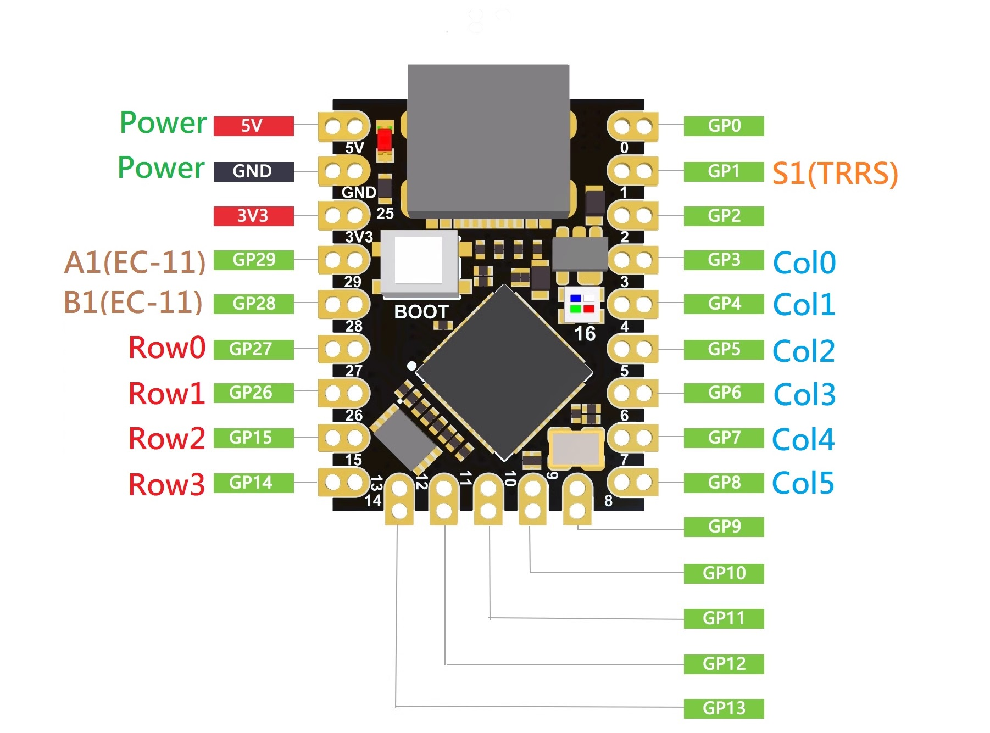
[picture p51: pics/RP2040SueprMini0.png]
|`RP2040-Zero`, `RP2040Supermini`, `RP2040-Matrix`||

> **Warning**
>
> `Elite-C`, `ProMicro` have same count of IOPins; `RP2040-Zero`, `RP2040Supermini`, `RP2040-Matrix` also too.

> **Note**
>
> Next, connect the wires from the MCU to the body board in order, and then connect the body to the external wires.
> 
> Please follow your own handwiring skills to connect the wires step by step, the way I do it is to assemble the wires combine arrays and then connect them to the corresponding sites.

- Connect TRRS jack:

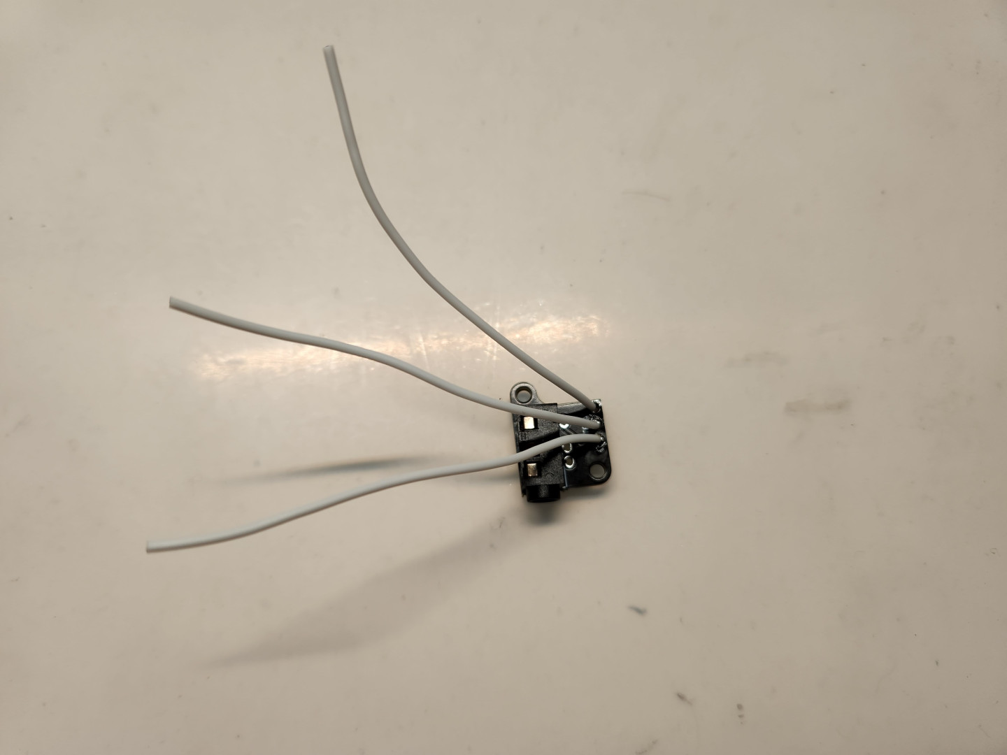
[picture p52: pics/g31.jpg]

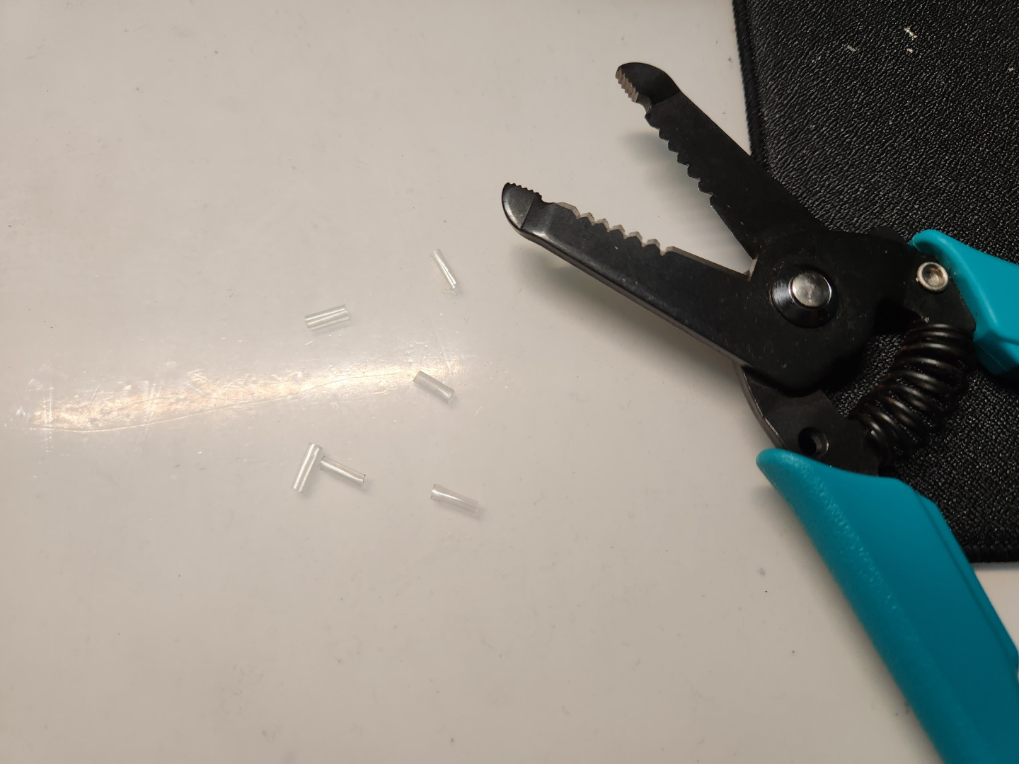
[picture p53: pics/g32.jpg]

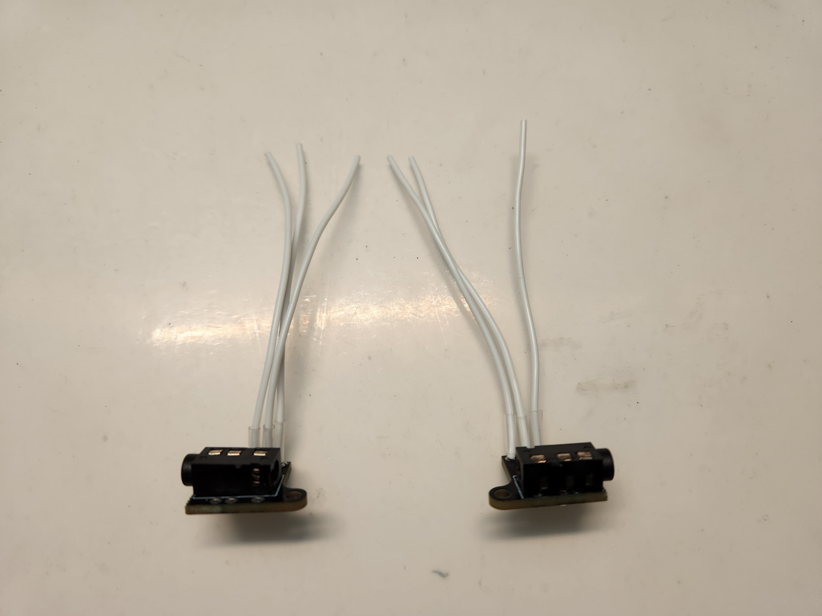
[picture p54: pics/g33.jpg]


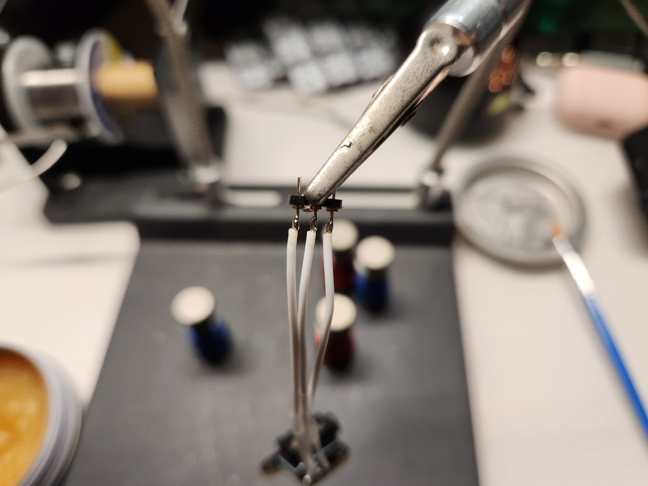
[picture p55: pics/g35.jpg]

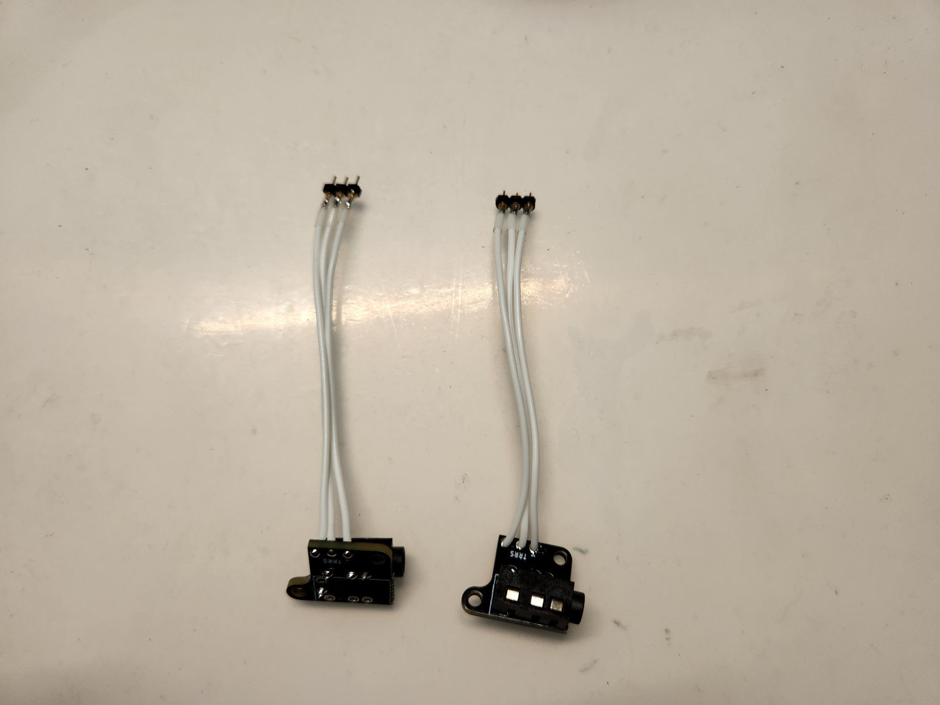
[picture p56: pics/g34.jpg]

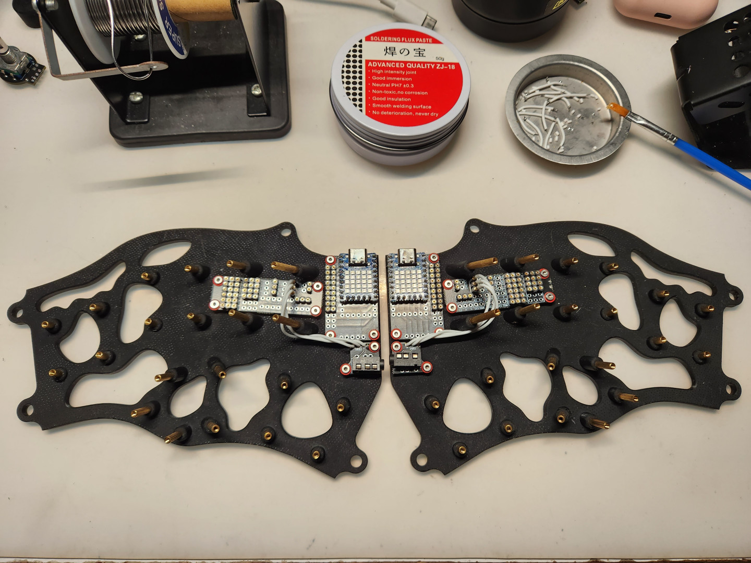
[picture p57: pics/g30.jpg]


- Give Power onto the body board:

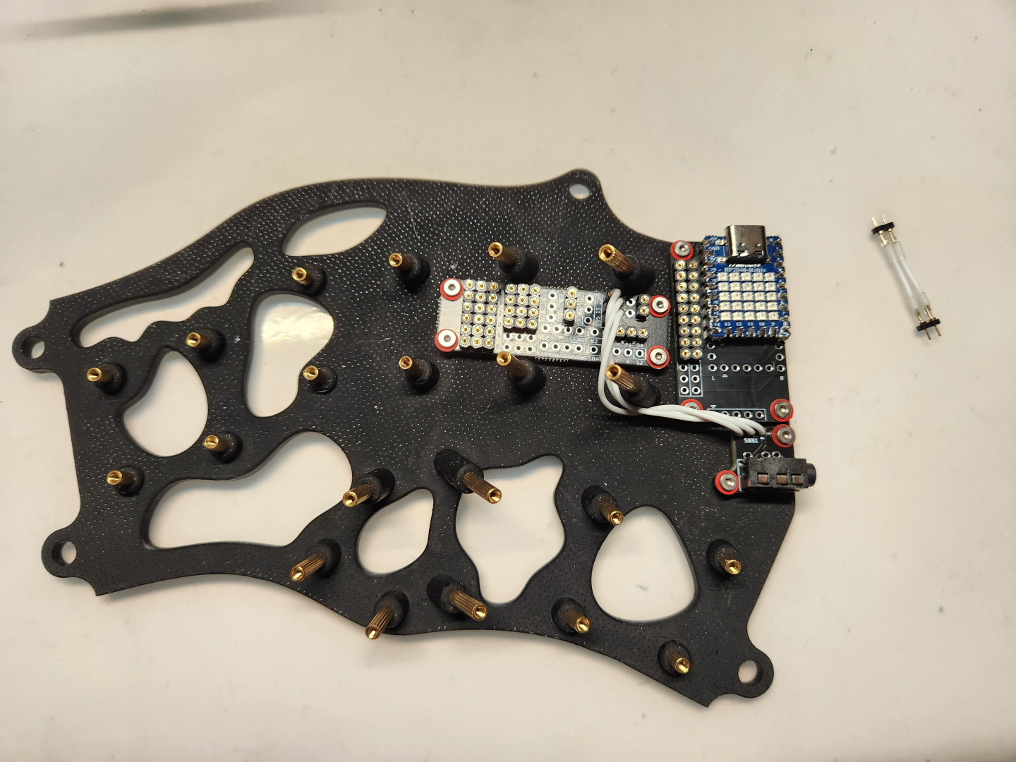
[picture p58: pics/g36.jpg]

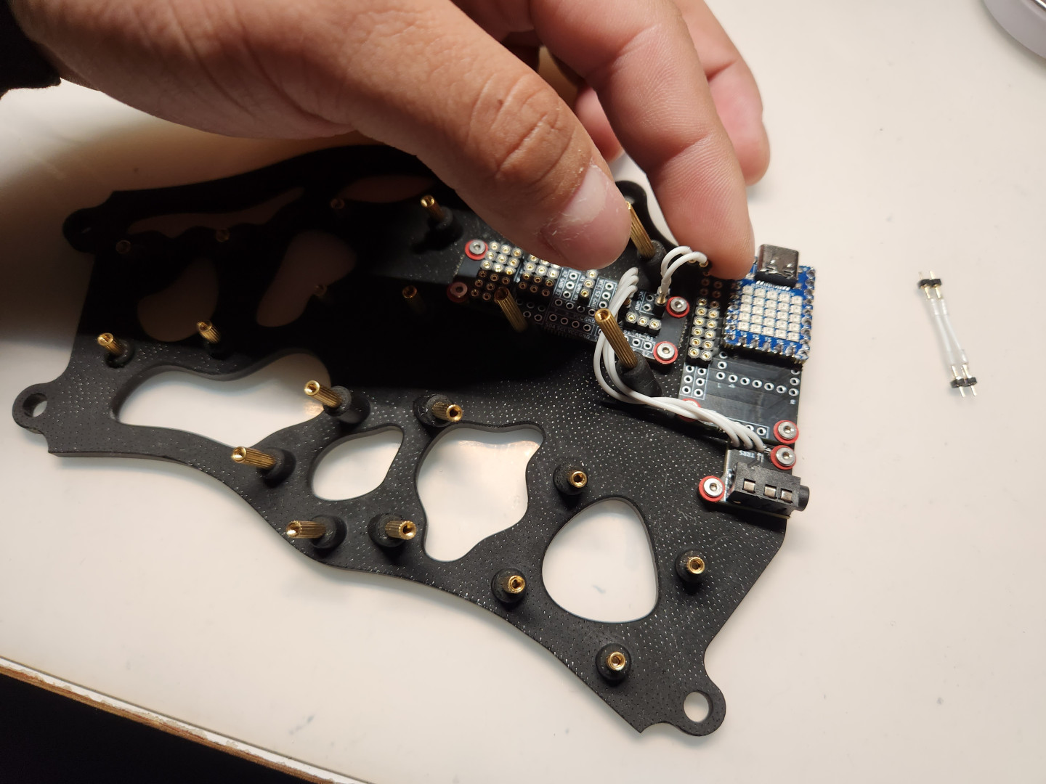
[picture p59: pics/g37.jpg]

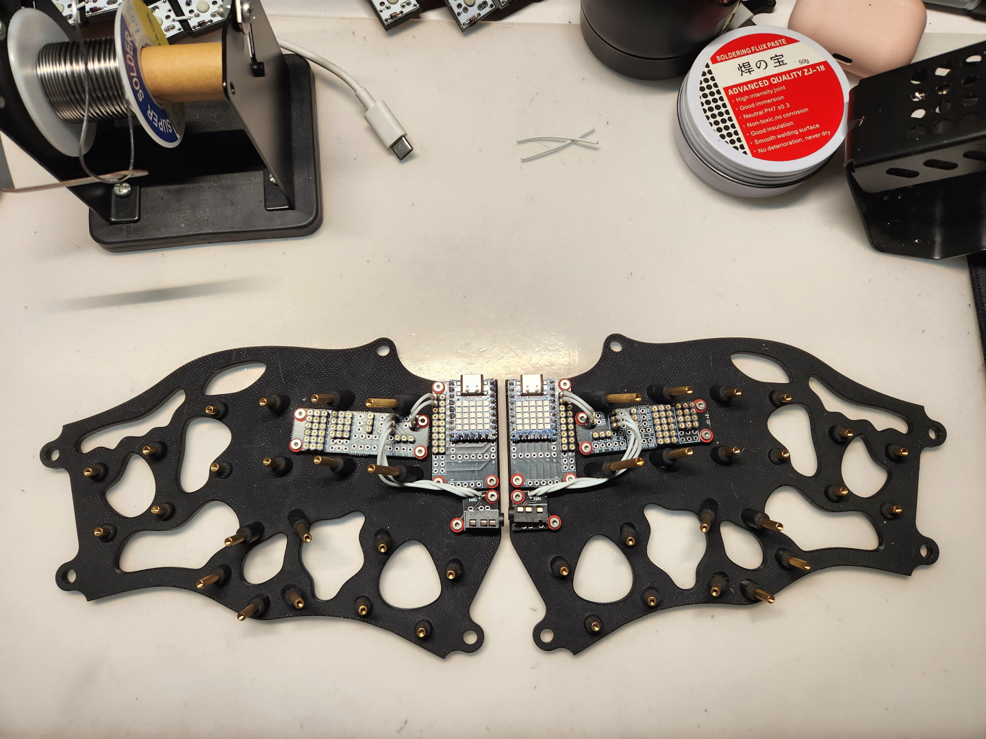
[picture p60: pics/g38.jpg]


- MCU to Signal, and connect EC-11: (I forgot to take Signal photo...)

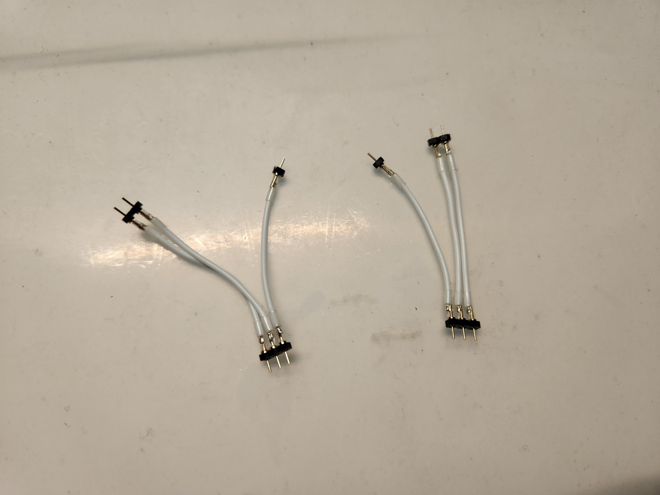
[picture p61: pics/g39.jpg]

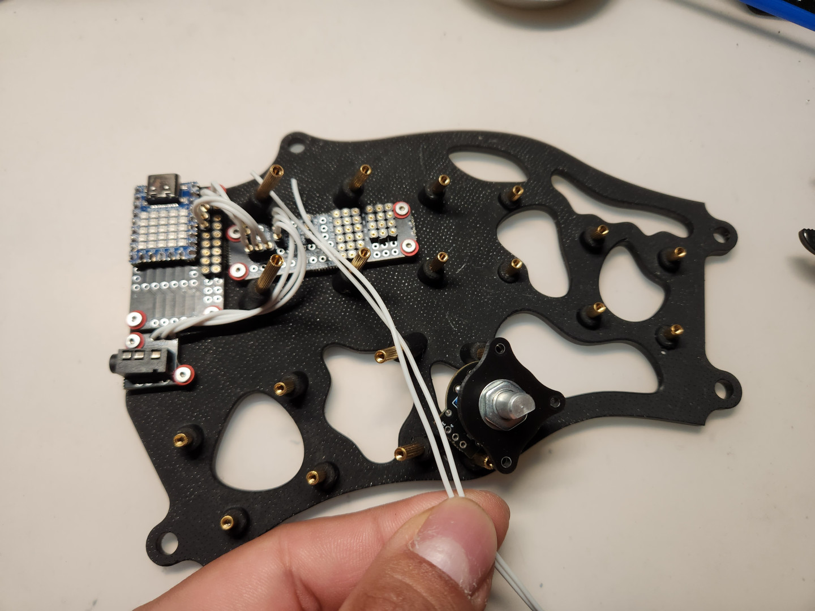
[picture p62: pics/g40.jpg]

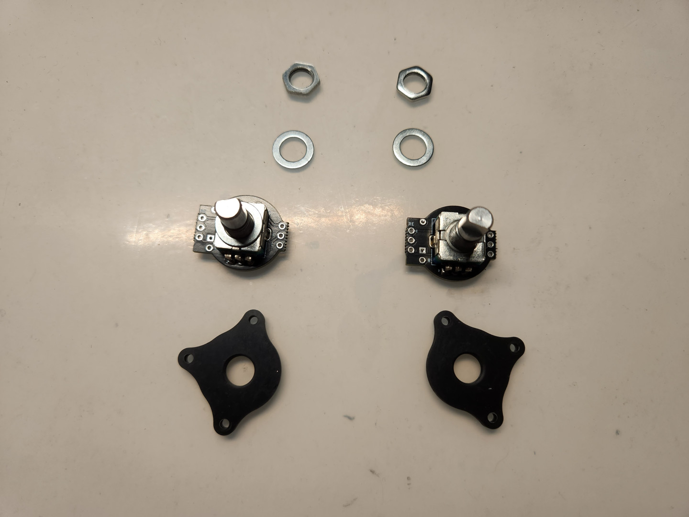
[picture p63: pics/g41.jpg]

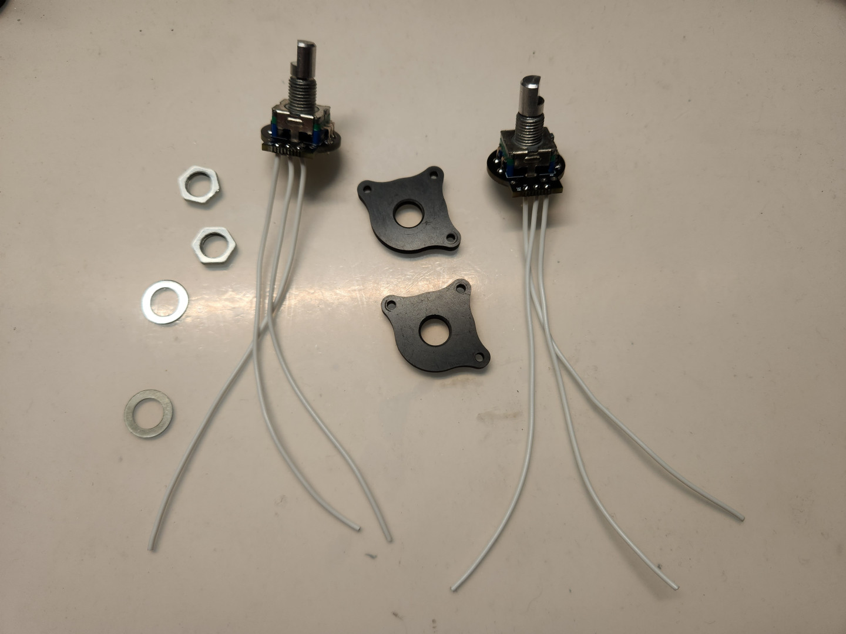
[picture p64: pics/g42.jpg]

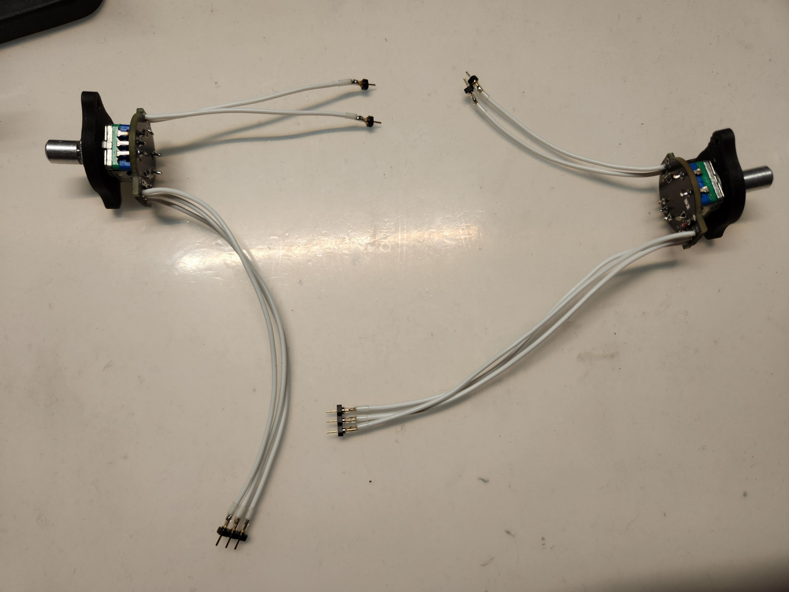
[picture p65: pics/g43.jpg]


- Matrix of EC-11:




- Matrix of Col0-1, Row0-2 (little finger area):





- Matrix of Col3-5, Row3 (Thumb area):





- Matrix of Col2-5, Row0-2 (Main area):





- Then finish other hand side:



- Testing keyboard, matrix and RGB led work.



- Put on your keycaps, then all done.



## Tending

> **Note**
>
> The MagWave44 has two ways to add the tending at different angles, one is by using the M5 screws in the 4 corners around the keyboard, and the other is by using the Magsafe rings, which need to be combined with the Magsafe tripod.

- Magsafe rings:





- M5 screws tending:




- Magsafe tripod and crema tripod.





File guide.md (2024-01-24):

# 組裝說明

- 中文說明（Chinese Guide）。
- [英文說明（English Guide）](guide_en.md)。

## 前置作業

- 列印完所有鍵盤需要的部件後，首先將底板及銅柱拿出來，並依照照片指示將銅柱安裝到適當的位置上。



- 接著將鍵軸安裝到定位板上，完成後再將它們暫時放一邊。





## 二極體及單格電路板

- 這裡簡單說明單格電路板上的二極體方向，請按照下圖將二極體安裝到單格電路板上。




- 接著將二極體用焊錫固定好，再剪去多餘的腳。




- 再來將已經完工的單格電路板安裝到定位板上焊接固定。




- EC-11電路板上還有一個按鈕，不要忘記將二極體接上去。




- 接好二極體後，可以先將旋鈕固定在板子上備著。



## 連結矩陣

- 下圖是MagWave44的矩陣圖，由於定位板合計分成6塊，首先我們需要將圖中的單格電路板用電線接起來。



- 完成後會是這樣的感覺。



## 電路板

> **Note**
>
> 主體電路板的部分包含`MCU`、`本體`、`TRRS`、`EC-11`，請先將他們備著。



- MCU電路板的部分因為它沒有分正反面，你可以任意調整方向，這次是安裝分離式鍵盤，匯流排線接口的部分分別朝向左右邊。



- 接著將MCU（這裡我是使用`RP2040-Matrix`做為主控）按照理想的方式固定在MCU電路板上。



> **Note**
>
> 將MCU固定在MCU電路板上後，`左側的引腳`會導向`L側`匯流排、`右側`會導向`R側`、`下方`會導向下方的`D側`，`箭頭`的方向為該針腳的位置，作為方向判讀。

- 接著再將`TRRS座`也焊接固定在專用的PCB板上。



> **Note**
>
> MCU左右邊有幾個可使用的IOPin，就焊接多少母排針座到匯流排線座的標示上。

> **Note**
>
> 下圖是本體電路板的主要功能說明，MagWave44會用到`Power`、`TRRS`（`VCC`、`S1`、`GND`）、`Signal`（`S1`、`A1`、`B1`）、`Rotray Encoder`（`A1`、`GND`、`B1`）及`Matrix`（`Row`及`Col`）的部分，並將左右邊本體電路板相應的排針母座焊接固定好。





- 然後將它們分別用`M2x8mm螺絲`、`M2螺帽`固定在底板上。（這裡我有搭配`墊片`，可視需求使用）



## 接線原理

> **Note**
>
> 如果是想依照MagWave44`相應的韌體`進行接線的話，下圖會說明各類MCU要如何接線比較輕鬆容易：

|微控制器|示意圖|
|---|---|
|`ATMega32U4 ProMicro`、`Elite-C`||
|`RP2040 ProMicro`系列||
|`RP2040-Zero`、`RP2040Supermini`、`RP2040-Matrix `||

> **Warning**
>
> `ProMicro`、`Elite-C`有著相同的IOPin；`RP2040-Zero`、`RP2040Supermini`、`RP2040-Matrix `三者也一樣。

> **Note**
>
> 接著按照順序將MCU上的線路接到本體板上，再將本體向外接線接出去。
> 
> 請依照自己的手拉線技巧將線路一步步接起來，我的方式是將電線組合成排線，再將它們接到相應的位置上。

- 連結TRRS座:









- 給鍵盤本體供電:





- 連結MCU到Signal，還有旋鈕EC-11: （我忘了拍照...）







- EC-11旋鈕的矩陣圖:




- 小指區域的矩陣圖:





- 拇指區域的矩陣位置:





- 最後將主要按鍵區域裝上去:





- 然後完成另一支手：



- 接著測試鍵盤按鍵、矩陣及旋鈕有沒有正常運作。



- 最後把鍵帽安裝上去就完成了。



## 鍵盤腳撐

> **Note**
>
> MagWave44有2種方式自行添加不同角度的腳撐，一種是是M5螺絲安裝在鍵盤周圍的4個角落，一種是使用Magsafe引磁片，需要搭配Magsafe雲台座合併使用。

- Magsafe引磁片：





- M5螺絲腳撐




- Magsafe雲台座，搭配雲台配件使用：





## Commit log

2024-01-17 update files
    [1x3 thumb plate.step, 1x3 thumb plate.stl, 3x2 main plate.step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]
2024-01-17 update PCB file and readme.md
2024-01-17 update pcb
    [4th-B_Cu.gbr, 4th-B_Mask.gbr, 4th-B_Paste.gbr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]
2024-01-24 renew files and pics
    [main-B_Cu.gbr, main-B_Mask.gbr, main-B_Paste.gbr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]
